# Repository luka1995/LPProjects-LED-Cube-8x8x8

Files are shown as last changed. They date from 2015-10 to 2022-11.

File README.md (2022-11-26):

## LPProjects LED Cube 8x8x8
### 3-Dimensional Display controllable with Smart Phone



Created by Luka Penger<br/>
<br/>
• Real Time controllable via network<br/>
• Universal power supply 5-12V DC<br/>
• Custom animations and effects<br/>
• Drawing with touch in X, Y and Z orientation<br/>
• Programmable sequences<br/>
• WEB interface for quick control<br/>
• Open UDP / TCP protocol<br/>
• Auto start function<br/>
• 32 MB Flash storage for animations<br/>
• Control multiple cubes<br/>
• iPhone / iPod Touch / iPad Application<br/>
• 3D preview animation<br/>
• Share animations with friends<br/>
• Spice up your party!<br/>
<br/>
Connect to your LPProjects LED Cube 8x8x8 with mobile device and makes awesome animations!<br/>

### iOS Application:
Compatible with iPhone 4, iPhone 4S, iPhone 5, iPhone 6, iPhone 6+, iPod touch, iPad. Requires iOS 7.0 or later.
<br/>
Available on: https://itunes.apple.com/us/app/led-cube-8x8x8-controller/id940731753

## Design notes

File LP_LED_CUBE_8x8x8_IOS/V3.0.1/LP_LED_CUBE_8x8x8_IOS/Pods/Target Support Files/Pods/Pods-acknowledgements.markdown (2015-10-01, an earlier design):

# Acknowledgements
This application makes use of the following third party libraries:

## CocoaAsyncSocket

Public Domain License

The CocoaAsyncSocket project is in the public domain.

The original TCP version (AsyncSocket) was created by Dustin Voss in January 2003.
Updated and maintained by Deusty LLC and the Apple development community.

## MBProgressHUD

Copyright (c) 2013 Matej Bukovinski

Permission is hereby granted, free of charge, to any person obtaining a copy
of this software and associated documentation files (the "Software"), to deal
in the Software without restriction, including without limitation the rights
to use, copy, modify, merge, publish, distribute, sublicense, and/or sell
copies of the Software, and to permit persons to whom the Software is
furnished to do so, subject to the following conditions:

The above copyright notice and this permission notice shall be included in
all copies or substantial portions of the Software.

THE SOFTWARE IS PROVIDED "AS IS", WITHOUT WARRANTY OF ANY KIND, EXPRESS OR
IMPLIED, INCLUDING BUT NOT LIMITED TO THE WARRANTIES OF MERCHANTABILITY,
FITNESS FOR A PARTICULAR PURPOSE AND NONINFRINGEMENT. IN NO EVENT SHALL THE
AUTHORS OR COPYRIGHT HOLDERS BE LIABLE FOR ANY CLAIM, DAMAGES OR OTHER
LIABILITY, WHETHER IN AN ACTION OF CONTRACT, TORT OR OTHERWISE, ARISING FROM,
OUT OF OR IN CONNECTION WITH THE SOFTWARE OR THE USE OR OTHER DEALINGS IN
THE SOFTWARE.

## RMPickerViewController

Copyright (c) 2013 Roland Moers

Permission is hereby granted, free of charge, to any person obtaining a copy
of this software and associated documentation files (the "Software"), to deal
in the Software without restriction, including without limitation the rights
to use, copy, modify, merge, publish, distribute, sublicense, and/or sell
copies of the Software, and to permit persons to whom the Software is
furnished to do so, subject to the following conditions:

The above copyright notice and this permission notice shall be included in
all copies or substantial portions of the Software.

THE SOFTWARE IS PROVIDED "AS IS", WITHOUT WARRANTY OF ANY KIND, EXPRESS OR
IMPLIED, INCLUDING BUT NOT LIMITED TO THE WARRANTIES OF MERCHANTABILITY,
FITNESS FOR A PARTICULAR PURPOSE AND NONINFRINGEMENT. IN NO EVENT SHALL THE
AUTHORS OR COPYRIGHT HOLDERS BE LIABLE FOR ANY CLAIM, DAMAGES OR OTHER
LIABILITY, WHETHER IN AN ACTION OF CONTRACT, TORT OR OTHERWISE, ARISING FROM,
OUT OF OR IN CONNECTION WITH THE SOFTWARE OR THE USE OR OTHER DEALINGS IN
THE SOFTWARE.

## Reachability

Copyright (c) 2011, Tony Million.
All rights reserved.

Redistribution and use in source and binary forms, with or without modification, are permitted provided that the following conditions are met:

1. Redistributions of source code must retain the above copyright notice, this list of conditions and the following disclaimer.

2. Redistributions in binary form must reproduce the above copyright notice, this list of conditions and the following disclaimer in the documentation and/or other materials provided with the distribution.

THIS SOFTWARE IS PROVIDED BY THE COPYRIGHT HOLDERS AND CONTRIBUTORS "AS IS" AND ANY EXPRESS OR IMPLIED WARRANTIES, INCLUDING, BUT NOT LIMITED TO, THE IMPLIED WARRANTIES OF MERCHANTABILITY AND FITNESS FOR A PARTICULAR PURPOSE ARE DISCLAIMED. IN NO EVENT SHALL THE COPYRIGHT HOLDER OR CONTRIBUTORS BE LIABLE FOR ANY DIRECT, INDIRECT, INCIDENTAL, SPECIAL, EXEMPLARY, OR CONSEQUENTIAL DAMAGES (INCLUDING, BUT NOT LIMITED TO, PROCUREMENT OF SUBSTITUTE GOODS OR SERVICES; LOSS OF USE, DATA, OR PROFITS; OR BUSINESS INTERRUPTION) HOWEVER CAUSED AND ON ANY THEORY OF LIABILITY, WHETHER IN CONTRACT, STRICT LIABILITY, OR TORT (INCLUDING NEGLIGENCE OR OTHERWISE) ARISING IN ANY WAY OUT OF THE USE OF THIS SOFTWARE, EVEN IF ADVISED OF THE POSSIBILITY OF SUCH DAMAGE. 

Generated by CocoaPods - http://cocoapods.org

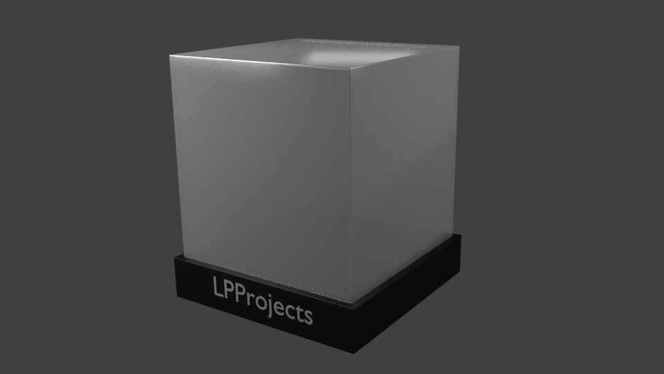
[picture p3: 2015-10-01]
Images/LED_Cube_8x8x8.png

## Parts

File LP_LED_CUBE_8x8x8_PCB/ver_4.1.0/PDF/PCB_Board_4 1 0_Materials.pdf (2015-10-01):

Item | Name / Description | Package | Designator on schematic | Quantity
1 | 74HC574N D-TYPE FLIP-FLOP | DIP-20 | U1, U2, U3, U4, U5, U6, U7, U8 | 8
2 | SI3861BDV Vishay 4.5-20V 2.3A Load Switch | TSOP-6 | U9, U10, U11, U12, U13, U14, U15, U16 | 8
3 | TPS56528 Step-Down Converter 4.5V-18V 5A | HSOP-8 | U17 | 1
4 | 100uH 2A Power Inductor 12x12mm | / | L1 | 1
5 | 3.81mm 2 pin Male Terminal Block Vertical | / | P8 | 1
6 | 2.54mm 2 pin Male Header Jumper | / | W1 | 1
7 | 2.54mm 2x8 pin IDC Female Header Connector | / | P6 | 5
8 | 2.54mm 2x4 pin IDC Female Header Connector | / | P5 | 2
9 | SK54 40V 5A SMC Schottky Diode SMD | SMC | D1 | 1
10 | 3mm LED Red | / | D2 | 1
11 | 220uF 16V Aluminium Electrolytic Capacitor 6.3x7.7mm | / | C25, C28 | 2
12 | 100nF | 0603 | C1, C2, C3, C4, C5, C6, C7, C8, C9, C11, C13, C15, C17, C19, C21, C23, | 18
13 | 1nF | 0603 | C10, C12, C14, C16, C18, C20, C22,C24 | 8
14 | 220uF | 0603 | C30 | 1
15 | 10k | 0603 | R65, R66, R69, R70, R71, R72, R75, R76, R77, R78, R81, R82, R83, R84, R87, R88, | 17
16 | 100R | 0603 | R1, R2, R3, R4, R5, R6, R7, R8, R9, R10, R11, R12, R13, R14, R15, R16, R17, R18, R19, R20, R21, R22, R23, R24, R25, R26, R27, R28, R29, R30, R31, R32, R33, R34, R35, R36, R37, R38, R39, R40, R41, R42, | 64
17 | 0R | 0603 | R67, R68, R73, R74, R79, R80, R85, R86 | 8
18 | 180k | 0603 | R90 | 1
19 | 220k | 0603 | R91 | 1
20 | 49.9k 1% | 0603 | R92 | 1
21 | 100k | 0603 | R93 | 1
22 | 470R | 0603 | R94 | 1

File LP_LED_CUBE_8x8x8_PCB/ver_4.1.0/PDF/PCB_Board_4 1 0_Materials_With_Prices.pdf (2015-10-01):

Item | Name / Description | Package | Designator on schematic | Quantity | Unit Price [Eur] | Part Number | Other
1 | 74HC574N D-TYPE FLIP-FLOP | DIP-20 | U1, U2, U3, U4, U5, U6, U7, U8 | 8 | 0,23 | 9591630 | Farnell
2 | SI3861BDV Vishay 4.5-20V 2.3A Load Switch | TSOP-6 | U9, U10, U11, U12, U13, U14, U15, U16 | 8 | 0,742 | 781-SI3861BDV-T1-E3 | Mouser
3 | TPS56528 Step-Down Converter 4.5V-18V 5A | HSOP-8 | U17 | 1 | 3,56 | 595-TPS56528DDA | Mouser
4 | 100uH 2A Power Inductor 12x12mm | / | L1 | 1 | 0,35 | 390302128027 | Ebay
5 | 3.81mm 2 pin Male Terminal Block Vertical | / | P8 | 1 | 0,25 | 301017793034 | Ebay
6 | 2.54mm 2 pin Male Header Jumper | / | W1 | 1 | 0,1 | 170910122061 | Ebay
7 | 2.54mm 2x8 pin IDC Female Header Connector | / | P6 | 5 | 0,15 | 171048488166 | Ebay
8 | 2.54mm 2x4 pin IDC Female Header Connector | / | P5 | 2 | 0,15 | 171046688738 | Ebay
9 | SK54 40V 5A SMC Schottky Diode SMD | SMC | D1 | 1 | 0,02 | 171055989918 | Ebay
10 | 3mm LED Red | / | D2 | 1 | 0,001 | 290809722053 | Ebay
11 | 220uF 16V Aluminium Electrolytic Capacitor 6.3x7.7mm | / | C25, C28 | 2 | 0,2 | 271673966101 | Ebay
12 | 100nF | 0603 | C1, C2, C3, C4, C5, C6, C7, C8, C9, C11, C13, C15, C17, C19, C21, C23, | 18 | 0,002 | / | Ebay
13 | 1nF | 0603 | C10, C12, C14, C16, C18, C20, C22,C24 | 8 | 0,002 | / | Ebay
14 | 220uF | 0603 | C30 | 1 | 0,002 | / | Ebay
15 | 10k | 0603 | R65, R66, R69, R70, R71, R72, R75, R76, R77, R78, R81, R82, R83, R84, R87, R88, | 17 | 0,002 | / | Ebay
16 | 100R | 0603 | R1, R2, R3, R4, R5, R6, R7, R8, R9, R10, R11, R12, R13, R14, R15, R16, R17, R18, R19, R20, R21, R22, R23, R24, R25, R26, R27, R28, R29, R30, R31, R32, R33, R34, R35, R36, R37, R38, R39, R40, R41, R42, | 64 | 0,002 | / | Ebay
17 | 0R | 0603 | R67, R68, R73, R74, R79, R80, R85, R86 | 8 | 0,002 | / | Ebay
18 | 180k | 0603 | R90 | 1 | 0,002 | / | Ebay
19 | 220k | 0603 | R91 | 1 | 0,002 | / | Ebay
20 | 49.9k 1% | 0603 | R92 | 1 | 0,002 | / | Ebay
21 | 100k | 0603 | R93 | 1 | 0,002 | / | Ebay
22 | 470R | 0603 | R94 | 1 | 0,002 | / | Ebay
All elements | | 13,745
2Layer PCB 10cm x 15cm 1.6mm Green | 1 | 8,8 | / | iTeadStudio
TOTAL IN EUROS: | 22,545

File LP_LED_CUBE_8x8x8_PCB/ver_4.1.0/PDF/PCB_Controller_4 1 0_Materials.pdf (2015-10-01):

Item | Name / Description | Package | Designator on schematic | Quantity
1 | NXP LPC1769FBD100 - 32-bit ARM Cortex-M3 | LQFP-100 | U1 | 1
2 | Texas Instruments TRS3232CDR RS-232 | SOIC 16 Narrow | U2 | 1
3 | Adesto Technologies AT45DB321E-SHF-T | SOIC (EIAJ) 8S2 8 | U3 | 1
4 | Texas Instruments DP83848CVV PHY 10/100 | LQFP-48 | U5 | 1
5 | Texas Instruments LM2671M-3.3 Step Down | SOIC-8 Narrow | U6 | 1
6 | LINK-PP LPJ4514GENL - Ethernet connector | / | P4 | 1
7 | SMT Male Header IDC Connector 1.27mm 2x5 pin | / | P2 | 1
8 | USB Type-B Right Angle Female Connector | / | P3 | 1
9 | RS-232 Female Serial Connector DB9 | / | P1 | 1
10 | 5.5MM x 2.5MM Female DC Connector | / | P7 | 1
11 | 3.81mm 2 pin Male Terminal Block Vertical | / | P8 | 1
12 | 2.54mm 2 pin Male Header Jumper | / | W1 | 1
13 | 2.54mm 2x8 pin IDC Female Header Connector | / | P6 | 1
14 | 2.54mm 2x4 pin IDC Female Header Connector | / | P5 | 1
15 | Tactile Push Button 6x6mm Right Angle | / | S1 | 1
16 | 1N5819 SS14 Schottky Diode SMD | SS14 | D6, D7, D9 | 3
17 | 3mm LED Red | / | D1, D2, D3, D4, D5, D8 | 6
18 | 12 MHz SMD Crystal 5032 5x3.2mm | 5032 | Y2 | 1
19 | 32.768 kHz SMD Crystal FC-135 | FC-135 3.2x1.5mm | Y1 | 1
20 | 50 MHz SMD Oscillator ACT9200 5x7mm | ACT9200 5x7mm | Y3 | 1
23 | 3.6V DC 0.22F Supercapacitor | Bulk | BT1 | 1
24 | 220uF 16V Aluminium Electrolytic Capacitor 6.3x7.7mm | / | C22, C24 | 2
25 | 100nF | 0603 | C1, C2, C3, C4, C9, C10, C11, C14, C15, C16, C17, C18, C19, | 15
26 | 22pF | 0603 | C5, C6, C7, C8 | 4
27 | 18pF | 0603 | C12, C13 | 2
28 | 1uF | 0603 | C20 | 1
29 | 10nF | 0603 | C21 | 1
30 | 10k | 0603 | R1, R3, R4, R5, R6, R7, R8, R29 | 8
31 | 1k | 0603 | R9 | 1
32 | 470R | 0603 | R10, R11, R12, R13, R14, R25, R26, R36 | 8
33 | 1k5 | 0603 | R16 | 1
34 | 33R | 0603 | R17, R18 | 1
34 | 75R 1% | 0603 | R19, R24, R27, R28 | 4
35 | 49R9 1% | 0603 | R20, R21, R22, R23 | 4
36 | 2k2 | 0603 | R30, R31, R32, R33, R34 | 5
37 | 4k7 | 0603 | R35 | 1
38 | 50R | 0805 | R15 | 1

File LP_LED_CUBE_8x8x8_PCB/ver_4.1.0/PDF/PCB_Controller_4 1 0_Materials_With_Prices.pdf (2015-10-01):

Item | Name / Description | Package | Designator on schematic | Quantity | Unit Price [Eur] | Part Number | Other
1 | NXP LPC1769FBD100 - 32-bit ARM Cortex-M3 | LQFP-100 | U1 | 1 | 10,16 | 771-LPC1769FBD100551 | Mouser
2 | Texas Instruments TRS3232CDR RS-232 | SOIC 16 Narrow | U2 | 1 | 1,62 | 595-TRS3232CDR | Mouser
3 | Adesto Technologies AT45DB321E-SHF-T | SOIC (EIAJ) 8S2 8 | U3 | 1 | 2,57 | 988-AT45DB321E-SHF-T | Mouser
4 | Texas Instruments DP83848CVV PHY 10/100 | LQFP-48 | U5 | 1 | 4,69 | 926-DP83848CVVX/NOPB | Mouser
5 | Texas Instruments LM2671M-3.3 Step Down | SOIC-8 Narrow | U6 | 1 | 2,83 | 926-LM2671MX33NOPB | Mouser
6 | LINK-PP LPJ4514GENL - Ethernet connector | / | P4 | 1 | 1,8 | / | LINK-PP
7 | SMT Male Header IDC Connector 1.27mm 2x5 pin | / | P2 | 1 | 0,5 | 171560426679 | Ebay
8 | USB Type-B Right Angle Female Connector | / | P3 | 1 | 0,5 | 280782705985 | Ebay
9 | RS-232 Female Serial Connector DB9 | / | P1 | 1 | 0,2 | 300944843046 | Ebay
10 | 5.5MM x 2.5MM Female DC Connector | / | P7 | 1 | 0,2 | 161271021525 | Ebay
11 | 3.81mm 2 pin Male Terminal Block Vertical | / | P8 | 1 | 0,25 | 301017793034 | Ebay
12 | 2.54mm 2 pin Male Header Jumper | / | W1 | 1 | 0,1 | 170910122061 | Ebay
13 | 2.54mm 2x8 pin IDC Female Header Connector | / | P6 | 1 | 0,15 | 171048488166 | Ebay
14 | 2.54mm 2x4 pin IDC Female Header Connector | / | P5 | 1 | 0,15 | 171046688738 | Ebay
15 | Tactile Push Button 6x6mm Right Angle | / | S1 | 1 | 0,1 | 370412390814 | Ebay
16 | 1N5819 SS14 Schottky Diode SMD | SS14 | D6, D7, D9 | 3 | 0,02 | 191194484047 | Ebay
17 | 3mm LED Red | / | D1, D2, D3, D4, D5, D8 | 6 | 0,001 | 290809722053 | Ebay
18 | 12 MHz SMD Crystal 5032 5x3.2mm | 5032 | Y2 | 1 | 0,25 | 331220814055 | Ebay
19 | 32.768 kHz SMD Crystal FC-135 | FC-135 3.2x1.5mm | Y1 | 1 | 0,25 | 231291006714 | Ebay
20 | 50 MHz SMD Oscillator ACT9200 5x7mm | ACT9200 5x7mm | Y3 | 1 | 0,8 | 121367170907 | Ebay
23 | 3.6V DC 0.22F Supercapacitor | Bulk | BT1 | 1 | 2,4 | 598-EDLRD224H3R6C | Mouser
24 | 220uF 16V Aluminium Electrolytic Capacitor 6.3x7.7mm | / | C22, C24 | 2 | 0,2 | 271673966101 | Ebay
25 | 100nF | 0603 | C1, C2, C3, C4, C9, C10, C11, C14, C15, C16, C17, C18, C19, | 15 | 0,002 | / | /
26 | 22pF | 0603 | C5, C6, C7, C8 | 4 | 0,002 | / | /
27 | 18pF | 0603 | C12, C13 | 2 | 0,002 | / | /
28 | 1uF | 0603 | C20 | 1 | 0,002 | / | /
29 | 10nF | 0603 | C21 | 1 | 0,002 | / | /
30 | 10k | 0603 | R1, R3, R4, R5, R6, R7, R8, R29 | 8 | 0,002 | / | /
31 | 1k | 0603 | R9 | 1 | 0,002 | / | /
32 | 470R | 0603 | R10, R11, R12, R13, R14, R25, R26, R36 | 8 | 0,002 | / | /
33 | 1k5 | 0603 | R16 | 1 | 0,002 | / | /
34 | 33R | 0603 | R17, R18 | 1 | 0,002 | / | /
34 | 75R 1% | 0603 | R19, R24, R27, R28 | 4 | 0,002 | / | /
35 | 49R9 1% | 0603 | R20, R21, R22, R23 | 4 | 0,002 | / | /
36 | 2k2 | 0603 | R30, R31, R32, R33, R34 | 5 | 0,002 | / | /
37 | 4k7 | 0603 | R35 | 1 | 0,002 | / | /
38 | 50R | 0805 | R15 | 1 | 0,002 | / | /
All elements | | 30,1
2Layer PCB 10cm x 15cm 1.6mm Green | 1 | 8,8 | / | iTeadStudio
TOTAL IN EUROS: | 38,9

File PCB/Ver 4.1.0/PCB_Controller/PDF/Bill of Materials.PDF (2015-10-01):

Bill of Materials | Bill of Materials For Project [LP_LED_CUBE_8x8x8.PrjPcb] (No PCB Document Selected)
Source Data From: | LP_LED_CUBE_8x8x8.PrjPcb
Project: | | LP_LED_CUBE_8x8x8.PrjPcb
Variant: | | None
Creation Date: 30/12/14 | 00:37:15
Print Date: | 30-Dec-14 | 12:37:18 am
#Column Name Comment | #Column Name ErrDesignato r | Description | Quantity

Battery | BT1 | Multicell Battery | 1
100n | C1, C2, C3, C4, C9, C10, C11, C14, C15,
| C16, C17, C18, C19, C23, C25 | Capacitor | 15
22p | C5, C6, C7, C8 | Capacitor | 4
18p | C12, C13 | Capacitor | 2
1uF | C20 | Capacitor | 1
10n | C21 | Capacitor | 1
220uF | C22, C24 | Capacitor | 2
USB LED | D1 | Typical INFRARED GaAs LED | 1
LED1 | D2 | Typical INFRARED GaAs LED | 1
LED2 | D3 | Typical INFRARED GaAs LED | 1
LED4 | D4 | Typical INFRARED GaAs LED | 1
LED5 | D5 | Typical INFRARED GaAs LED | 1
1N5819 | D6, D7, D9 | Schottky Diode | 3
POWER LED | D8 | Typical INFRARED GaAs LED | 1
100uH | L1 | Inductor | 1
RS232 | P1 | Receptacle Assembly, 9 Position, Right
| | Angle | 1
JTAG Connector ULINK | P2 | JTAG Connector | 1
USB B | P3 | USB Connector | 1
RJ45 Ethernet | P4 | Ethernet Connector | 1
LED Layers Connector | P5 | Header, 4-Pin, Dual row | 1
LED Connector | P6 | Header, 8-Pin, Dual row | 1
DC Connector | P7 | DC Power Connector | 1
Power to board | P8 | Header, 2-Pin | 1
10k | R1, R3, R4, R5, R6, R7, R8, R29 | Resistor | 8
NO | R2 | Resistor | 1
1k | R9 | Resistor | 1
470R | R10, R11, R12, R13, R14, R25, R26, R36 | Resistor | 8
50R | R15 | Resistor | 1
1k5 | R16 | Resistor | 1
33R | R17, R18 | Resistor | 2
75R 1% | R19, R24, R27, R28 | Resistor | 4
49R9 1% | R20, R21, R22, R23 | Resistor | 4
2k2 | R30, R31, R32, R33, R34 | Resistor | 5
4k7 | R35 | Resistor | 1
FW Update | S1 | Switch | 1
LPC1769FBD10
0 | U1 | 32-bit ARM Cortex-M3 microcontroller; up to
| | 512 kB flash and 64 kB SRAM with
| | Ethernet, USB 2.0 Host/Device/OTG, CAN | 1
TRS3232 | U2 | Dual 232 +3V3 | 1
AT45DB321E | U3 | SPI Flash 32MB | 1
DP83848C | U4 | Ethernet PHY | 1
LM2671 - 3.3V | U5 | Switcher Voltage Regulator | 1
Jumper | W1 | Jumper Wire | 1
32.768 kHz | Y1 | Crystal Oscillator | 1
12 MHz | Y2 | Crystal Oscillator | 1
50 MHz | Y3 | | 1
Approved Notes | 90

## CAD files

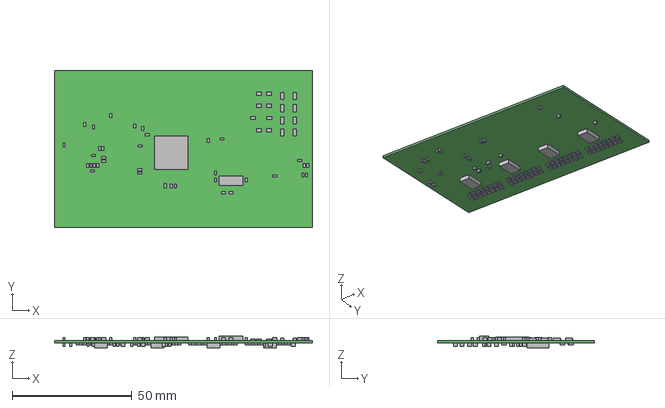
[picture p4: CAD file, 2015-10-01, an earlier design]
LP_LED_CUBE_8x8x8_PCB/ver_1.0.0/Project Outputs for LP_LED_CUBE_8x8x8/ExportSTEP/LP_LED_CUBE_8x8x8.step
107.7 x 65.5 x 4.98 mm
Board
Extruded x 142

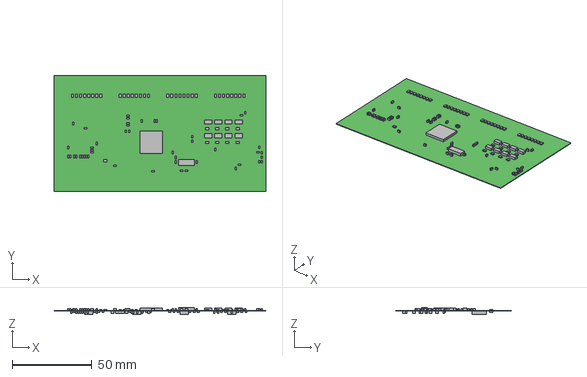
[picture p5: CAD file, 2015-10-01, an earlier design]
LP_LED_CUBE_8x8x8_PCB/ver_2.0.0/Project Outputs for LP_LED_CUBE_8x8x8/ExportSTEP/LP_LED_CUBE_8x8x8.step
132.7 x 72.6 x 4.30 mm
Board
Extruded x 157

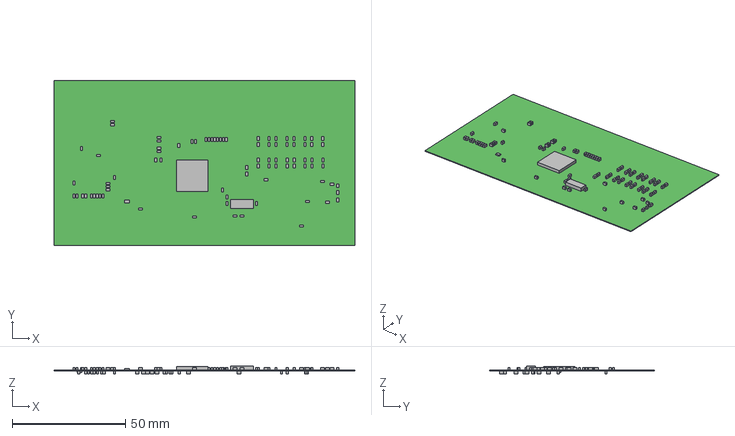
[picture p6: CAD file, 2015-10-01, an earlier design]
LP_LED_CUBE_8x8x8_PCB/ver_3.0.0/Project Outputs for LP_LED_CUBE_8x8x8/ExportSTEP/LP_LED_CUBE_8x8x8.step
132.7 x 72.6 x 3.60 mm
Board
Extruded x 117

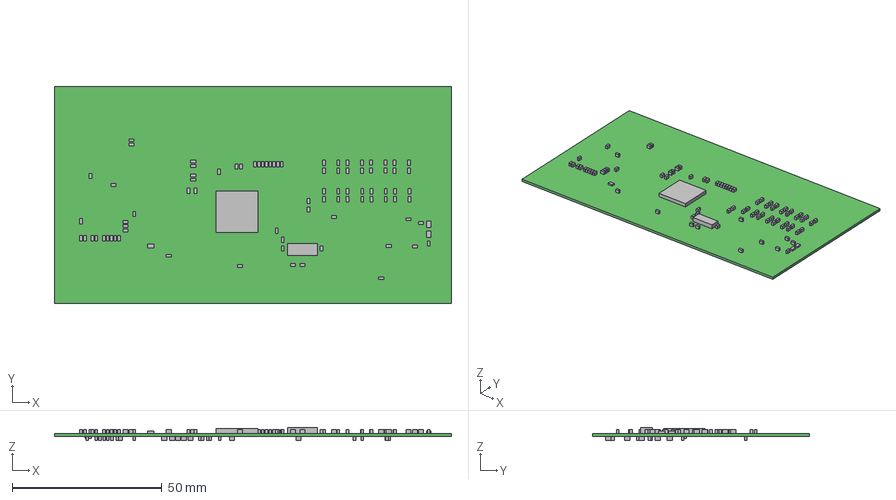
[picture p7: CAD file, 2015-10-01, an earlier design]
LP_LED_CUBE_8x8x8_PCB/ver_3.0.1/Project Outputs for LP_LED_CUBE_8x8x8/ExportSTEP/LP_LED_CUBE_8x8x8.step
132.7 x 72.6 x 4.28 mm
Board
Extruded x 117

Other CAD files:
LP_LED_CUBE_8x8x8_PCB/ver_4.0.0/PCB_Controller/Project Outputs for LP_LED_CUBE_8x8x8/ExportSTEP/LP_LED_CUBE_8x8x8.step
Images/LED_Cube_8x8x8.blend
Images/LED_Cube_Preview_V2.blend

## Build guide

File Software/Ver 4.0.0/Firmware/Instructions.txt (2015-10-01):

LPProjects LED Cube 8x8x8 Controller Firmware - Instructions

Version: 4.0.0

==================================================================

Changes in this version:
-	This is release version.

==================================================================

Hardware configuration/requirements:
-	A USB cable "Type B" to power the board and to access the USB Bootloader.

How to run Bootloader:
	1.	Connect USB cable “Type B” to Controller and Computer.
	2.	Hold the Firmware-Update/Reset button.
	3.	Connect the power to Controller.
	4.	Release the Firmware-Update/Reset button.
	
	5.	On the Computer you will see new MSC drive
	6.	Open the new MSC drive showing in “My Computer” (Windows workstation).
	7.	Delete the default “firmware.bin” file.
	8.	Copy the new binary (.bin) file on the drive.
	9.	Remove power supply from Controller.
	10.	Connect the power to Controller again.

	Now you have a new version of firmware loaded on the Controller.

==================================================================

Luka Penger 2014
http://lukapenger.eu

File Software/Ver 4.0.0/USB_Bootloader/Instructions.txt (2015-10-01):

LPProjects LED Cube 8x8x8 Controller USB Bootloader - Instructions

Version: 4.0.0

==================================================================

Hardware configuration/requirements:
-	Connect JTAG to 5x2 pin connector.

How to program .hex to Controlller:

-	You may create a µVision3 project for Flash download of a HEX file as described below:

-	Create a µVision project file with the menu command Project — New Project....

-	Select the microcontroller for your project from the Device Database, but do not copy any Startup Code to this project.

-	In the dialog Project — Options for Target — Output enter the HEX file name as Name of Executable.

-	Setup the download utility as described under Configure Flash Menu.

-	Flash Download Button

-	When using the Flash — Download command, µVision is programming the specified HEX file into the Flash ROM device.

==================================================================

Luka Penger 2014
http://lukapenger.eu

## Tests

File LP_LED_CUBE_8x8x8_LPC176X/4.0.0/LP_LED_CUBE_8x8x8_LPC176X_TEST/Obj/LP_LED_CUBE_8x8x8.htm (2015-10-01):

# Static Call Graph for image .\Obj\LP_LED_CUBE_8x8x8.axf

#<CALLGRAPH># ARM Linker, 5.03 [Build 76]: Last Updated: Sat Nov 29 20:14:07 2014

### Maximum Stack Usage = 80 bytes + Unknown(Functions without stacksize, Cycles, Untraceable Function Pointers)

### Call chain for Maximum Stack Depth:

__rt_entry_main ⇒ main ⇒ LED_CUBE_Animation_String_belt ⇒ LED_CUBE_Animation_Set_char_to_belt ⇒ tolower ⇒ __rt_ctype_table

### Functions with no stack information

- __user_initial_stackheap

### Mutually Recursive functions

- NMI_Handler ⇒ NMI_Handler
- HardFault_Handler ⇒ HardFault_Handler
- MemManage_Handler ⇒ MemManage_Handler
- BusFault_Handler ⇒ BusFault_Handler
- UsageFault_Handler ⇒ UsageFault_Handler
- SVC_Handler ⇒ SVC_Handler
- DebugMon_Handler ⇒ DebugMon_Handler
- PendSV_Handler ⇒ PendSV_Handler
- ADC_IRQHandler ⇒ ADC_IRQHandler

### Function Pointers

- ADC_IRQHandler from startup_lpc17xx.o(.text) referenced from startup_lpc17xx.o(RESET)
- BOD_IRQHandler from startup_lpc17xx.o(.text) referenced from startup_lpc17xx.o(RESET)
- BusFault_Handler from startup_lpc17xx.o(.text) referenced from startup_lpc17xx.o(RESET)
- CANActivity_IRQHandler from startup_lpc17xx.o(.text) referenced from startup_lpc17xx.o(RESET)
- CAN_IRQHandler from startup_lpc17xx.o(.text) referenced from startup_lpc17xx.o(RESET)
- DMA_IRQHandler from startup_lpc17xx.o(.text) referenced from startup_lpc17xx.o(RESET)
- DebugMon_Handler from startup_lpc17xx.o(.text) referenced from startup_lpc17xx.o(RESET)
- EINT0_IRQHandler from startup_lpc17xx.o(.text) referenced from startup_lpc17xx.o(RESET)
- EINT1_IRQHandler from startup_lpc17xx.o(.text) referenced from startup_lpc17xx.o(RESET)
- EINT2_IRQHandler from startup_lpc17xx.o(.text) referenced from startup_lpc17xx.o(RESET)
- EINT3_IRQHandler from startup_lpc17xx.o(.text) referenced from startup_lpc17xx.o(RESET)
- ENET_IRQHandler from startup_lpc17xx.o(.text) referenced from startup_lpc17xx.o(RESET)
- HardFault_Handler from startup_lpc17xx.o(.text) referenced from startup_lpc17xx.o(RESET)
- I2C0_IRQHandler from startup_lpc17xx.o(.text) referenced from startup_lpc17xx.o(RESET)
- I2C1_IRQHandler from startup_lpc17xx.o(.text) referenced from startup_lpc17xx.o(RESET)
- I2C2_IRQHandler from startup_lpc17xx.o(.text) referenced from startup_lpc17xx.o(RESET)
- I2S_IRQHandler from startup_lpc17xx.o(.text) referenced from startup_lpc17xx.o(RESET)
- MCPWM_IRQHandler from startup_lpc17xx.o(.text) referenced from startup_lpc17xx.o(RESET)
- MemManage_Handler from startup_lpc17xx.o(.text) referenced from startup_lpc17xx.o(RESET)
- NMI_Handler from startup_lpc17xx.o(.text) referenced from startup_lpc17xx.o(RESET)
- PLL0_IRQHandler from startup_lpc17xx.o(.text) referenced from startup_lpc17xx.o(RESET)
- PLL1_IRQHandler from startup_lpc17xx.o(.text) referenced from startup_lpc17xx.o(RESET)
- PWM1_IRQHandler from startup_lpc17xx.o(.text) referenced from startup_lpc17xx.o(RESET)
- PendSV_Handler from startup_lpc17xx.o(.text) referenced from startup_lpc17xx.o(RESET)
- QEI_IRQHandler from startup_lpc17xx.o(.text) referenced from startup_lpc17xx.o(RESET)
- RIT_IRQHandler from startup_lpc17xx.o(.text) referenced from startup_lpc17xx.o(RESET)
- RTC_IRQHandler from startup_lpc17xx.o(.text) referenced from startup_lpc17xx.o(RESET)
- Reset_Handler from startup_lpc17xx.o(.text) referenced from startup_lpc17xx.o(RESET)
- SPI_IRQHandler from startup_lpc17xx.o(.text) referenced from startup_lpc17xx.o(RESET)
- SSP0_IRQHandler from startup_lpc17xx.o(.text) referenced from startup_lpc17xx.o(RESET)
- SSP1_IRQHandler from startup_lpc17xx.o(.text) referenced from startup_lpc17xx.o(RESET)
- SVC_Handler from startup_lpc17xx.o(.text) referenced from startup_lpc17xx.o(RESET)
- SysTick_Handler from main.o(.text) referenced from startup_lpc17xx.o(RESET)
- SystemInit from system_lpc17xx.o(.text) referenced from startup_lpc17xx.o(.text)
- TIMER0_IRQHandler from startup_lpc17xx.o(.text) referenced from startup_lpc17xx.o(RESET)
- TIMER1_IRQHandler from startup_lpc17xx.o(.text) referenced from startup_lpc17xx.o(RESET)
- TIMER2_IRQHandler from startup_lpc17xx.o(.text) referenced from startup_lpc17xx.o(RESET)
- TIMER3_IRQHandler from startup_lpc17xx.o(.text) referenced from startup_lpc17xx.o(RESET)
- UART0_IRQHandler from uart.o(.text) referenced from startup_lpc17xx.o(RESET)
- UART1_IRQHandler from uart.o(.text) referenced from startup_lpc17xx.o(RESET)
- UART2_IRQHandler from startup_lpc17xx.o(.text) referenced from startup_lpc17xx.o(RESET)
- UART3_IRQHandler from startup_lpc17xx.o(.text) referenced from startup_lpc17xx.o(RESET)
- USBActivity_IRQHandler from startup_lpc17xx.o(.text) referenced from startup_lpc17xx.o(RESET)
- USB_IRQHandler from startup_lpc17xx.o(.text) referenced from startup_lpc17xx.o(RESET)
- UsageFault_Handler from startup_lpc17xx.o(.text) referenced from startup_lpc17xx.o(RESET)
- WDT_IRQHandler from startup_lpc17xx.o(.text) referenced from startup_lpc17xx.o(RESET)
- __main from __main.o(!!!main) referenced from startup_lpc17xx.o(.text)
- _get_lc_ctype from lc_ctype_c.o(locale$$code) referenced from rt_ctype_table.o(.text)

### Global Symbols

__main (Thumb, 8 bytes, Stack size 0 bytes, __main.o(!!!main))

[Calls]

- >> __rt_entry
- >> __scatterload

__scatterload (Thumb, 0 bytes, Stack size unknown bytes, __scatter.o(!!!scatter))

[Called By]

- >> __main

__scatterload_rt2 (Thumb, 44 bytes, Stack size unknown bytes, __scatter.o(!!!scatter), UNUSED)

[Calls]

- >> __rt_entry

__scatterload_rt2_thumb_only (Thumb, 0 bytes, Stack size unknown bytes, __scatter.o(!!!scatter), UNUSED)

__scatterload_null (Thumb, 0 bytes, Stack size unknown bytes, __scatter.o(!!!scatter), UNUSED)

__scatterload_copy (Thumb, 26 bytes, Stack size unknown bytes, __scatter_copy.o(!!handler_copy), UNUSED)

[Calls]

- >> __scatterload_copy

[Called By]

- >> __scatterload_copy

__scatterload_zeroinit (Thumb, 28 bytes, Stack size unknown bytes, __scatter_zi.o(!!handler_zi), UNUSED)

__rt_lib_init (Thumb, 0 bytes, Stack size unknown bytes, libinit.o(.ARM.Collect$$libinit$$00000000))

[Called By]

- >> __rt_entry_li

__rt_lib_init_fp_1 (Thumb, 0 bytes, Stack size unknown bytes, libinit2.o(.ARM.Collect$$libinit$$00000002))

__rt_lib_init_heap_1 (Thumb, 0 bytes, Stack size unknown bytes, libinit2.o(.ARM.Collect$$libinit$$00000008))

__rt_lib_init_rand_2 (Thumb, 0 bytes, Stack size unknown bytes, libinit2.o(.ARM.Collect$$libinit$$0000000B))

[Stack]

- Max Depth = 8 + Unknown Stack Size
- Call Chain = __rt_lib_init_rand_2 ⇒ _rand_init ⇒ srand

[Calls]

- >> _rand_init

__rt_lib_init_user_alloc_1 (Thumb, 0 bytes, Stack size unknown bytes, libinit2.o(.ARM.Collect$$libinit$$0000000A))

__rt_lib_init_lc_common (Thumb, 0 bytes, Stack size unknown bytes, libinit2.o(.ARM.Collect$$libinit$$0000000D))

[Calls]

- >> __rt_locale

__rt_lib_init_rand_1 (Thumb, 0 bytes, Stack size unknown bytes, libinit2.o(.ARM.Collect$$libinit$$0000000C))

__rt_lib_init_lc_collate_1 (Thumb, 0 bytes, Stack size unknown bytes, libinit2.o(.ARM.Collect$$libinit$$0000000F))

__rt_lib_init_lc_ctype_2 (Thumb, 0 bytes, Stack size unknown bytes, libinit2.o(.ARM.Collect$$libinit$$00000010))

[Stack]

- Max Depth = 8 + Unknown Stack Size
- Call Chain = __rt_lib_init_lc_ctype_2 ⇒ _get_lc_ctype

[Calls]

- >> _get_lc_ctype

__rt_lib_init_alloca_1 (Thumb, 0 bytes, Stack size unknown bytes, libinit2.o(.ARM.Collect$$libinit$$0000002C))

__rt_lib_init_argv_1 (Thumb, 0 bytes, Stack size unknown bytes, libinit2.o(.ARM.Collect$$libinit$$0000002A))

__rt_lib_init_atexit_1 (Thumb, 0 bytes, Stack size unknown bytes, libinit2.o(.ARM.Collect$$libinit$$00000019))

__rt_lib_init_clock_1 (Thumb, 0 bytes, Stack size unknown bytes, libinit2.o(.ARM.Collect$$libinit$$0000001F))

__rt_lib_init_cpp_1 (Thumb, 0 bytes, Stack size unknown bytes, libinit2.o(.ARM.Collect$$libinit$$00000030))

__rt_lib_init_exceptions_1 (Thumb, 0 bytes, Stack size unknown bytes, libinit2.o(.ARM.Collect$$libinit$$0000002E))

__rt_lib_init_fp_trap_1 (Thumb, 0 bytes, Stack size unknown bytes, libinit2.o(.ARM.Collect$$libinit$$0000001D))

__rt_lib_init_getenv_1 (Thumb, 0 bytes, Stack size unknown bytes, libinit2.o(.ARM.Collect$$libinit$$00000021))

__rt_lib_init_lc_ctype_1 (Thumb, 0 bytes, Stack size unknown bytes, libinit2.o(.ARM.Collect$$libinit$$00000011))

__rt_lib_init_lc_monetary_1 (Thumb, 0 bytes, Stack size unknown bytes, libinit2.o(.ARM.Collect$$libinit$$00000013))

__rt_lib_init_lc_numeric_1 (Thumb, 0 bytes, Stack size unknown bytes, libinit2.o(.ARM.Collect$$libinit$$00000015))

__rt_lib_init_lc_time_1 (Thumb, 0 bytes, Stack size unknown bytes, libinit2.o(.ARM.Collect$$libinit$$00000017))

__rt_lib_init_return (Thumb, 0 bytes, Stack size unknown bytes, libinit2.o(.ARM.Collect$$libinit$$00000031))

__rt_lib_init_signal_1 (Thumb, 0 bytes, Stack size unknown bytes, libinit2.o(.ARM.Collect$$libinit$$0000001B))

__rt_lib_init_stdio_1 (Thumb, 0 bytes, Stack size unknown bytes, libinit2.o(.ARM.Collect$$libinit$$00000023))

__rt_lib_shutdown (Thumb, 0 bytes, Stack size unknown bytes, libshutdown.o(.ARM.Collect$$libshutdown$$00000000))

[Called By]

- >> __rt_exit_ls

__rt_lib_shutdown_fp_trap_1 (Thumb, 0 bytes, Stack size unknown bytes, libshutdown2.o(.ARM.Collect$$libshutdown$$00000006))

__rt_lib_shutdown_heap_1 (Thumb, 0 bytes, Stack size unknown bytes, libshutdown2.o(.ARM.Collect$$libshutdown$$0000000E))

__rt_lib_shutdown_return (Thumb, 0 bytes, Stack size unknown bytes, libshutdown2.o(.ARM.Collect$$libshutdown$$0000000F))

__rt_lib_shutdown_signal_1 (Thumb, 0 bytes, Stack size unknown bytes, libshutdown2.o(.ARM.Collect$$libshutdown$$00000009))

__rt_lib_shutdown_stdio_1 (Thumb, 0 bytes, Stack size unknown bytes, libshutdown2.o(.ARM.Collect$$libshutdown$$00000003))

__rt_lib_shutdown_user_alloc_1 (Thumb, 0 bytes, Stack size unknown bytes, libshutdown2.o(.ARM.Collect$$libshutdown$$0000000B))

__rt_entry (Thumb, 0 bytes, Stack size unknown bytes, rtentry.o(.ARM.Collect$$rtentry$$00000000))

[Called By]

- >> __main
- >> __scatterload_rt2

__rt_entry_presh_1 (Thumb, 0 bytes, Stack size unknown bytes, rtentry2.o(.ARM.Collect$$rtentry$$00000002))

__rt_entry_sh (Thumb, 0 bytes, Stack size unknown bytes, rtentry4.o(.ARM.Collect$$rtentry$$00000004))

[Stack]

- Max Depth = 8 + Unknown Stack Size
- Call Chain = __rt_entry_sh ⇒ __user_setup_stackheap

[Calls]

- >> __user_setup_stackheap

__rt_entry_li (Thumb, 0 bytes, Stack size unknown bytes, rtentry2.o(.ARM.Collect$$rtentry$$0000000A))

[Calls]

- >> __rt_lib_init

__rt_entry_postsh_1 (Thumb, 0 bytes, Stack size unknown bytes, rtentry2.o(.ARM.Collect$$rtentry$$00000009))

__rt_entry_main (Thumb, 0 bytes, Stack size unknown bytes, rtentry2.o(.ARM.Collect$$rtentry$$0000000D))

[Stack]

- Max Depth = 80 + Unknown Stack Size
- Call Chain = __rt_entry_main ⇒ main ⇒ LED_CUBE_Animation_String_belt ⇒ LED_CUBE_Animation_Set_char_to_belt ⇒ tolower ⇒ __rt_ctype_table

[Calls]

- >> main
- >> exit

__rt_entry_postli_1 (Thumb, 0 bytes, Stack size unknown bytes, rtentry2.o(.ARM.Collect$$rtentry$$0000000C))

__rt_exit (Thumb, 0 bytes, Stack size unknown bytes, rtexit.o(.ARM.Collect$$rtexit$$00000000))

[Called By]

- >> exit

__rt_exit_ls (Thumb, 0 bytes, Stack size unknown bytes, rtexit2.o(.ARM.Collect$$rtexit$$00000003))

[Calls]

- >> __rt_lib_shutdown

__rt_exit_prels_1 (Thumb, 0 bytes, Stack size unknown bytes, rtexit2.o(.ARM.Collect$$rtexit$$00000002))

__rt_exit_exit (Thumb, 0 bytes, Stack size unknown bytes, rtexit2.o(.ARM.Collect$$rtexit$$00000004))

[Calls]

- >> _sys_exit

rand (Thumb, 48 bytes, Stack size 0 bytes, rand.o(.emb_text), UNUSED)

[Called By]

- >> LED_CUBE_Animations_Cube_invaders
- >> LED_CUBE_Animations_Cube_sonic
- >> LED_CUBE_Animations_Cube_stars
- >> LED_CUBE_Animation_Cube_2_auto
- >> LED_CUBE_Random

UART_CONSOLE_Init (Thumb, 10 bytes, Stack size 0 bytes, main.o(.text))

[Stack]

- Max Depth = 32
- Call Chain = UART_CONSOLE_Init ⇒ UART_Init

[Calls]

- >> UART_Init

[Called By]

- >> Init

UART_CONSOLE_Send_Buffer (Thumb, 10 bytes, Stack size 0 bytes, main.o(.text), UNUSED)

[Calls]

- >> UART_SendBuffer

UART_CONSOLE_Send_String (Thumb, 22 bytes, Stack size 8 bytes, main.o(.text))

[Stack]

- Max Depth = 32
- Call Chain = UART_CONSOLE_Send_String ⇒ UART_SendBuffer ⇒ UART_SendChar

[Calls]

- >> strlen
- >> UART_SendBuffer

[Called By]

- >> Init

UART_CONSOLE_Send_Char (Thumb, 8 bytes, Stack size 0 bytes, main.o(.text), UNUSED)

[Calls]

- >> UART_SendChar

Status_LEDs_Init (Thumb, 36 bytes, Stack size 0 bytes, main.o(.text))

[Called By]

- >> Init

Status_LED1_Set (Thumb, 24 bytes, Stack size 0 bytes, main.o(.text))

[Called By]

- >> main
- >> Status_LED1_Toggle

Status_LED2_Set (Thumb, 24 bytes, Stack size 0 bytes, main.o(.text))

[Called By]

- >> main
- >> Status_LED2_Toggle

Status_LED1_Toggle (Thumb, 10 bytes, Stack size 0 bytes, main.o(.text), UNUSED)

[Calls]

- >> Status_LED1_Set

Status_LED2_Toggle (Thumb, 10 bytes, Stack size 0 bytes, main.o(.text), UNUSED)

[Calls]

- >> Status_LED2_Set

SysTick_Handler (Thumb, 94 bytes, Stack size 16 bytes, main.o(.text))

[Stack]

- Max Depth = 32
- Call Chain = SysTick_Handler ⇒ LED_CUBE_Timer

[Calls]

- >> LED_CUBE_Timer

[Address Reference Count : 1]

- startup_lpc17xx.o(RESET)

Init (Thumb, 66 bytes, Stack size 8 bytes, main.o(.text))

[Stack]

- Max Depth = 40
- Call Chain = Init ⇒ UART_CONSOLE_Send_String ⇒ UART_SendBuffer ⇒ UART_SendChar

[Calls]

- >> SystemInit
- >> LED_CUBE_Init
- >> Status_LEDs_Init
- >> UART_CONSOLE_Send_String
- >> UART_CONSOLE_Init

[Called By]

- >> main

main (Thumb, 70 bytes, Stack size 0 bytes, main.o(.text))

[Stack]

- Max Depth = 80
- Call Chain = main ⇒ LED_CUBE_Animation_String_belt ⇒ LED_CUBE_Animation_Set_char_to_belt ⇒ tolower ⇒ __rt_ctype_table

[Calls]

- >> LED_CUBE_Animations_wipe
- >> LED_CUBE_Animations_Cubes_4
- >> LED_CUBE_Animations_Cube_waves
- >> LED_CUBE_Animation_String_to_front
- >> LED_CUBE_Animation_String_belt
- >> Init
- >> Status_LED2_Set
- >> Status_LED1_Set

[Called By]

- >> __rt_entry_main

LED_CUBE_Layers_Set (Thumb, 180 bytes, Stack size 0 bytes, led_cube_8x8x8.o(.text))

[Called By]

- >> LED_CUBE_Frame_show
- >> LED_CUBE_Timer

LED_CUBE_Layer_Set (Thumb, 172 bytes, Stack size 0 bytes, led_cube_8x8x8.o(.text))

[Called By]

- >> LED_CUBE_Frame_show
- >> LED_CUBE_Timer

LED_CUBE_Clock_Set (Thumb, 168 bytes, Stack size 0 bytes, led_cube_8x8x8.o(.text))

[Called By]

- >> LED_CUBE_Frame_show
- >> LED_CUBE_Timer

LED_CUBE_Outputs_Set (Thumb, 196 bytes, Stack size 0 bytes, led_cube_8x8x8.o(.text))

[Called By]

- >> LED_CUBE_Frame_show
- >> LED_CUBE_Timer

LED_CUBE_Frame_show (Thumb, 92 bytes, Stack size 24 bytes, led_cube_8x8x8.o(.text), UNUSED)

[Calls]

- >> Delay_us
- >> LED_CUBE_Outputs_Set
- >> LED_CUBE_Clock_Set
- >> LED_CUBE_Layer_Set
- >> LED_CUBE_Layers_Set

LED_CUBE_Timer (Thumb, 98 bytes, Stack size 16 bytes, led_cube_8x8x8.o(.text))

[Stack]

- Max Depth = 16
- Call Chain = LED_CUBE_Timer

[Calls]

- >> Delay_us
- >> LED_CUBE_Outputs_Set
- >> LED_CUBE_Clock_Set
- >> LED_CUBE_Layer_Set
- >> LED_CUBE_Layers_Set

[Called By]

- >> SysTick_Handler

LED_CUBE_Clear (Thumb, 30 bytes, Stack size 8 bytes, led_cube_8x8x8.o(.text))

[Stack]

- Max Depth = 8
- Call Chain = LED_CUBE_Clear

[Called By]

- >> rotate_90_deg
- >> rotate_90_auto
- >> LED_CUBE_Animations_Cube_stripes
- >> LED_CUBE_Animations_Cube_invaders
- >> LED_CUBE_Animations_Show_belt
- >> LED_CUBE_Animtions_Outline_shrink
- >> LED_CUBE_Animations_Cube_sonic
- >> LED_CUBE_Animations_Cube_Outline
- >> LED_CUBE_Animations_Cube_stars
- >> LED_CUBE_Animations_Outline_shrink
- >> LED_CUBE_Animations_Cubes_2
- >> LED_CUBE_Animation_Cube_2_auto
- >> LED_CUBE_Animation_Set_char_to_belt
- >> LED_CUBE_Animation_Show_belt
- >> LED_CUBE_Init
- >> LED_CUBE_Animations_Cubes_4
- >> LED_CUBE_Animations_Cube_waves
- >> LED_CUBE_Animation_String_to_front

LED_CUBE_Clear_layer (Thumb, 20 bytes, Stack size 0 bytes, led_cube_8x8x8.o(.text), UNUSED)

[Called By]

- >> LED_CUBE_Animations_Cube_2_auto_show

LED_CUBE_Full (Thumb, 30 bytes, Stack size 8 bytes, led_cube_8x8x8.o(.text), UNUSED)

LED_CUBE_Cube_3 (Thumb, 38 bytes, Stack size 0 bytes, led_cube_8x8x8.o(.text), UNUSED)

LED_CUBE_Cube_4_line (Thumb, 32 bytes, Stack size 0 bytes, led_cube_8x8x8.o(.text), UNUSED)

LED_CUBE_Random (Thumb, 48 bytes, Stack size 24 bytes, led_cube_8x8x8.o(.text), UNUSED)

[Calls]

- >> rand

LED_CUBE_Test_z (Thumb, 30 bytes, Stack size 8 bytes, led_cube_8x8x8.o(.text), UNUSED)

LED_CUBE_Test_y (Thumb, 16 bytes, Stack size 0 bytes, led_cube_8x8x8.o(.text))

[Called By]

- >> LED_CUBE_Animations_wipe

LED_CUBE_Test_x (Thumb, 18 bytes, Stack size 0 bytes, led_cube_8x8x8.o(.text), UNUSED)

LED_CUBE_Clocks_Set (Thumb, 180 bytes, Stack size 0 bytes, led_cube_8x8x8.o(.text), UNUSED)

LED_CUBE_Init (Thumb, 90 bytes, Stack size 0 bytes, led_cube_8x8x8.o(.text))

[Stack]

- Max Depth = 8
- Call Chain = LED_CUBE_Init ⇒ LED_CUBE_Clear

[Calls]

- >> LED_CUBE_Clear

[Called By]

- >> Init

LED_CUBE_Animation_Char (Thumb, 3550 bytes, Stack size 0 bytes, led_cube_8x8x8_animations.o(.text))

[Called By]

- >> LED_CUBE_Animation_Set_char_to_belt
- >> LED_CUBE_Animation_String_to_front

LED_CUBE_Animation_String_to_front (Thumb, 54 bytes, Stack size 16 bytes, led_cube_8x8x8_animations.o(.text))

[Stack]

- Max Depth = 32
- Call Chain = LED_CUBE_Animation_String_to_front ⇒ tolower ⇒ __rt_ctype_table

[Calls]

- >> tolower
- >> Delay_ms
- >> LED_CUBE_Animation_Char
- >> LED_CUBE_Clear

[Called By]

- >> main

LED_CUBE_Animation_Move_belt_left (Thumb, 22 bytes, Stack size 0 bytes, led_cube_8x8x8_animations.o(.text))

[Called By]

- >> LED_CUBE_Animation_String_belt

LED_CUBE_Animation_Show_belt (Thumb, 154 bytes, Stack size 24 bytes, led_cube_8x8x8_animations.o(.text))

[Stack]

- Max Depth = 32
- Call Chain = LED_CUBE_Animation_Show_belt ⇒ LED_CUBE_Clear

[Calls]

- >> Delay_ms
- >> LED_CUBE_Clear

[Called By]

- >> LED_CUBE_Animation_String_belt

LED_CUBE_Animation_Set_char_to_belt (Thumb, 82 bytes, Stack size 24 bytes, led_cube_8x8x8_animations.o(.text))

[Stack]

- Max Depth = 40
- Call Chain = LED_CUBE_Animation_Set_char_to_belt ⇒ tolower ⇒ __rt_ctype_table

[Calls]

- >> tolower
- >> LED_CUBE_Animation_Char
- >> LED_CUBE_Clear

[Called By]

- >> LED_CUBE_Animation_String_belt

LED_CUBE_Animation_String_belt (Thumb, 80 bytes, Stack size 40 bytes, led_cube_8x8x8_animations.o(.text))

[Stack]

- Max Depth = 80
- Call Chain = LED_CUBE_Animation_String_belt ⇒ LED_CUBE_Animation_Set_char_to_belt ⇒ tolower ⇒ __rt_ctype_table

[Calls]

- >> LED_CUBE_Animation_Set_char_to_belt
- >> LED_CUBE_Animation_Show_belt
- >> LED_CUBE_Animation_Move_belt_left

[Called By]

- >> main

LED_CUBE_Animations_Cube_2_auto_show (Thumb, 164 bytes, Stack size 32 bytes, led_cube_8x8x8_animations.o(.text), UNUSED)

[Calls]

- >> Delay_ms
- >> LED_CUBE_Clear_layer

[Called By]

- >> LED_CUBE_Animation_Cube_2_auto

LED_CUBE_Animations_Cube2_move_z_rev (Thumb, 36 bytes, Stack size 16 bytes, led_cube_8x8x8_animations.o(.text), UNUSED)

[Called By]

- >> LED_CUBE_Animation_Cube_2_auto

LED_CUBE_Animations_Cube2_move_z_fwd (Thumb, 36 bytes, Stack size 16 bytes, led_cube_8x8x8_animations.o(.text), UNUSED)

[Called By]

- >> LED_CUBE_Animation_Cube_2_auto

LED_CUBE_Animations_Cube2_move_x_rev (Thumb, 40 bytes, Stack size 12 bytes, led_cube_8x8x8_animations.o(.text), UNUSED)

[Called By]

- >> LED_CUBE_Animation_Cube_2_auto

LED_CUBE_Animations_Cube2_move_x_fwd (Thumb, 36 bytes, Stack size 12 bytes, led_cube_8x8x8_animations.o(.text), UNUSED)

[Called By]

- >> LED_CUBE_Animation_Cube_2_auto

LED_CUBE_Animations_Cube2_move_y_rev (Thumb, 40 bytes, Stack size 12 bytes, led_cube_8x8x8_animations.o(.text), UNUSED)

[Called By]

- >> LED_CUBE_Animation_Cube_2_auto

LED_CUBE_Animations_Cube2_move_y_fwd (Thumb, 36 bytes, Stack size 12 bytes, led_cube_8x8x8_animations.o(.text), UNUSED)

[Called By]

- >> LED_CUBE_Animation_Cube_2_auto

LED_CUBE_Animation_Cube_2_auto (Thumb, 468 bytes, Stack size 48 bytes, led_cube_8x8x8_animations.o(.text), UNUSED)

[Calls]

- >> rand
- >> LED_CUBE_Animations_Cube2_move_y_fwd
- >> LED_CUBE_Animations_Cube2_move_y_rev
- >> LED_CUBE_Animations_Cube2_move_x_fwd
- >> LED_CUBE_Animations_Cube2_move_x_rev
- >> LED_CUBE_Animations_Cube2_move_z_fwd
- >> LED_CUBE_Animations_Cube2_move_z_rev
- >> LED_CUBE_Animations_Cube_2_auto_show
- >> LED_CUBE_Clear

LED_CUBE_Animations_Cubes_2 (Thumb, 400 bytes, Stack size 8 bytes, led_cube_8x8x8_animations.o(.text), UNUSED)

[Calls]

- >> move_z_fwd
- >> move_y_rev
- >> move_y_fwd
- >> move_x_fwd
- >> Delay_ms
- >> LED_CUBE_Clear

LED_CUBE_Animations_wipe (Thumb, 82 bytes, Stack size 24 bytes, led_cube_8x8x8_animations.o(.text))

[Stack]

- Max Depth = 60
- Call Chain = LED_CUBE_Animations_wipe ⇒ move_y_rev

[Calls]

- >> move_y_rev
- >> Delay_ms
- >> LED_CUBE_Test_y

[Called By]

- >> main

LED_CUBE_Animations_explosion (Thumb, 188 bytes, Stack size 32 bytes, led_cube_8x8x8_animations.o(.text), UNUSED)

[Calls]

- >> Delay_ms

LED_CUBE_Animations_Outline_shrink (Thumb, 202 bytes, Stack size 8 bytes, led_cube_8x8x8_animations.o(.text), UNUSED)

[Calls]

- >> Delay_ms
- >> LED_CUBE_Clear

LED_CUBE_Animations_Cubes_4 (Thumb, 382 bytes, Stack size 8 bytes, led_cube_8x8x8_animations.o(.text))

[Stack]

- Max Depth = 44
- Call Chain = LED_CUBE_Animations_Cubes_4 ⇒ move_y_rev

[Calls]

- >> move_z_rev
- >> move_z_fwd
- >> move_y_rev
- >> move_y_fwd
- >> move_x_rev
- >> move_x_fwd
- >> Delay_ms
- >> LED_CUBE_Clear

[Called By]

- >> main

LED_CUBE_Animations_Cube_stars (Thumb, 86 bytes, Stack size 32 bytes, led_cube_8x8x8_animations.o(.text), UNUSED)

[Calls]

- >> rand
- >> Delay_ms
- >> LED_CUBE_Clear

LED_CUBE_Animations_Cube_Outline (Thumb, 256 bytes, Stack size 16 bytes, led_cube_8x8x8_animations.o(.text), UNUSED)

[Calls]

- >> rotate_90_auto
- >> Delay_ms
- >> LED_CUBE_Clear

LED_CUBE_Animations_Cube_waves (Thumb, 436 bytes, Stack size 16 bytes, led_cube_8x8x8_animations.o(.text))

[Stack]

- Max Depth = 48
- Call Chain = LED_CUBE_Animations_Cube_waves ⇒ move_x_rev

[Calls]

- >> move_x_rev
- >> Delay_ms
- >> LED_CUBE_Clear

[Called By]

- >> main

LED_CUBE_Animations_Cube_sonic (Thumb, 936 bytes, Stack size 40 bytes, led_cube_8x8x8_animations.o(.text), UNUSED)

[Calls]

- >> rand
- >> rotate_90_deg
- >> Delay_ms
- >> LED_CUBE_Clear

LED_CUBE_Animtions_Outline_shrink (Thumb, 196 bytes, Stack size 8 bytes, led_cube_8x8x8_animations.o(.text), UNUSED)

[Calls]

- >> Delay_ms
- >> LED_CUBE_Clear

LED_CUBE_Animations_Show_belt (Thumb, 154 bytes, Stack size 24 bytes, led_cube_8x8x8_animations.o(.text), UNUSED)

[Calls]

- >> Delay_ms
- >> LED_CUBE_Clear

invaders_move_right (Thumb, 250 bytes, Stack size 32 bytes, led_cube_8x8x8_animations.o(.text), UNUSED)

[Called By]

- >> invader_show_loop

invaders_move_left (Thumb, 252 bytes, Stack size 32 bytes, led_cube_8x8x8_animations.o(.text), UNUSED)

[Called By]

- >> invader_show_loop

invaders_move_down (Thumb, 158 bytes, Stack size 16 bytes, led_cube_8x8x8_animations.o(.text), UNUSED)

[Called By]

- >> invader_show_loop

LED_CUBE_Animations_Cube_invaders (Thumb, 340 bytes, Stack size 32 bytes, led_cube_8x8x8_animations.o(.text), UNUSED)

[Calls]

- >> rand
- >> move_z_rev
- >> move_z_fwd
- >> move_x_rev
- >> move_x_fwd
- >> Delay_ms
- >> invader_show_loop
- >> LED_CUBE_Clear

LED_CUBE_Animations_Cube_belt_wipe (Thumb, 90 bytes, Stack size 16 bytes, led_cube_8x8x8_animations.o(.text), UNUSED)

[Calls]

- >> Delay_ms

LED_CUBE_Animations_Cube_block_wipe (Thumb, 100 bytes, Stack size 16 bytes, led_cube_8x8x8_animations.o(.text), UNUSED)

[Calls]

- >> move_x_fwd
- >> Delay_ms

LED_CUBE_Animations_Cube_stripes (Thumb, 206 bytes, Stack size 24 bytes, led_cube_8x8x8_animations.o(.text), UNUSED)

[Calls]

- >> Delay_ms
- >> LED_CUBE_Clear

move_z_fwd (Thumb, 36 bytes, Stack size 20 bytes, led_cube_8x8x8_translation.o(.text))

[Stack]

- Max Depth = 20
- Call Chain = move_z_fwd

[Called By]
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

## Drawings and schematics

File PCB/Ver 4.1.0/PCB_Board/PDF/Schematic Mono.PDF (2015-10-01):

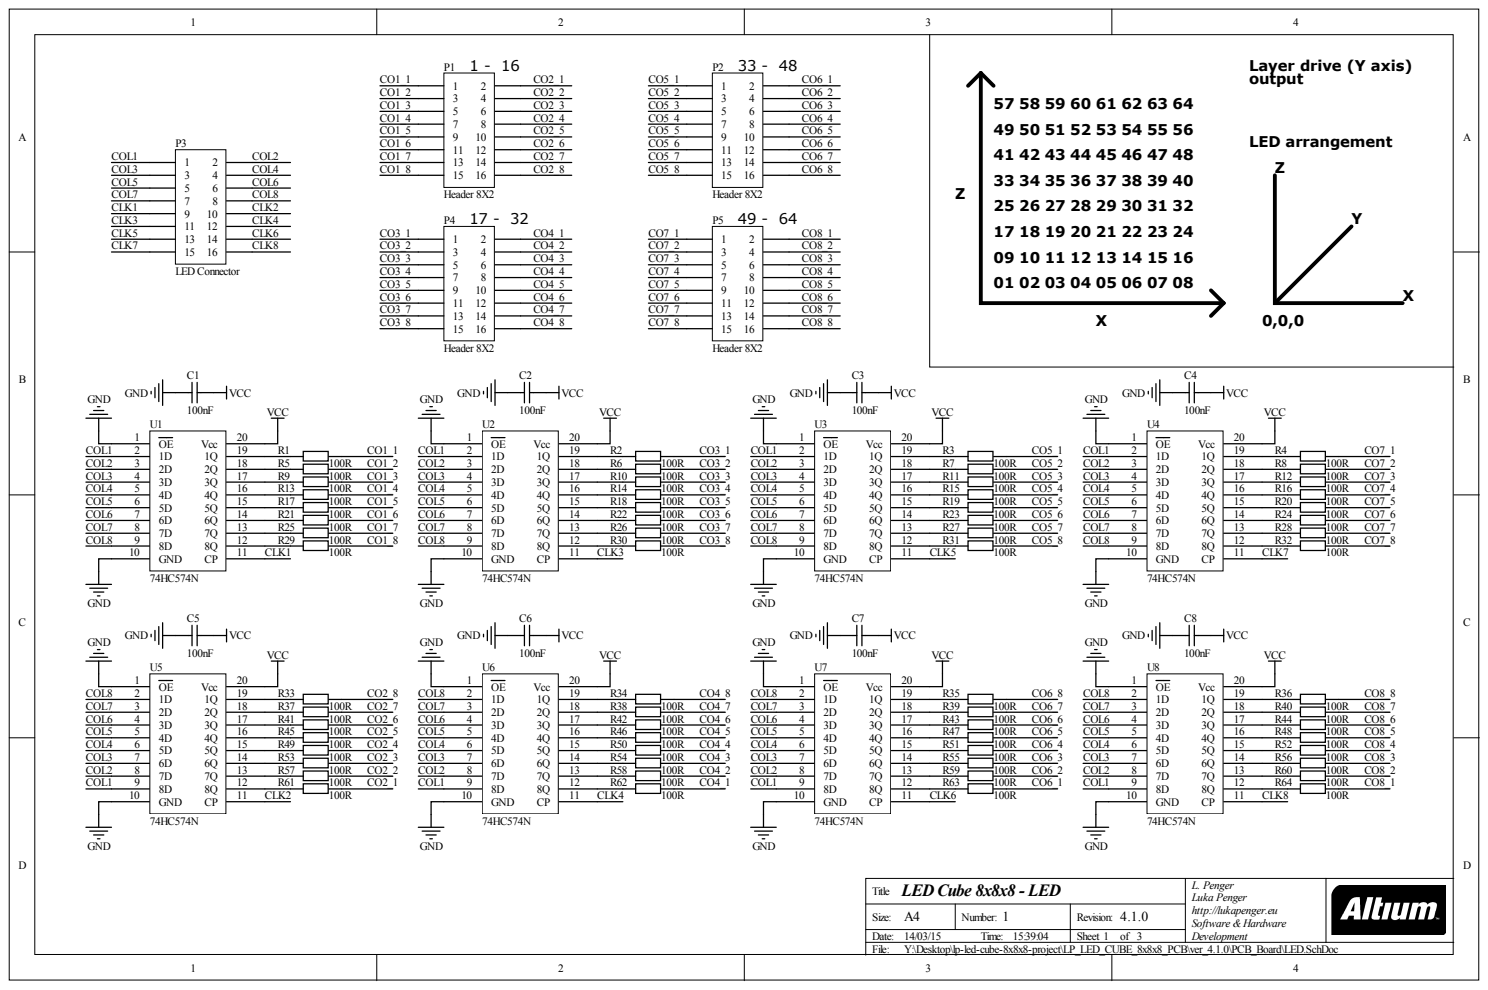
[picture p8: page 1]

Title LED Cube 8x8x8 - LED | L. Penger Luka Penger http://lukapenger.eu Software & Hardware Development

Size: A4 | Number: 1 | Revision: 4.1.0

1 2 | Date: 14/03/15 Time: 15:39:04 Sheet 1 of 3 File: Y:\Desktop\lp-led-cube-8x8x8-project\LP_LED_CUBE_8x8x8_PCB\ver_4.1.0\PCB_Board\LED.SchDoc 3 4

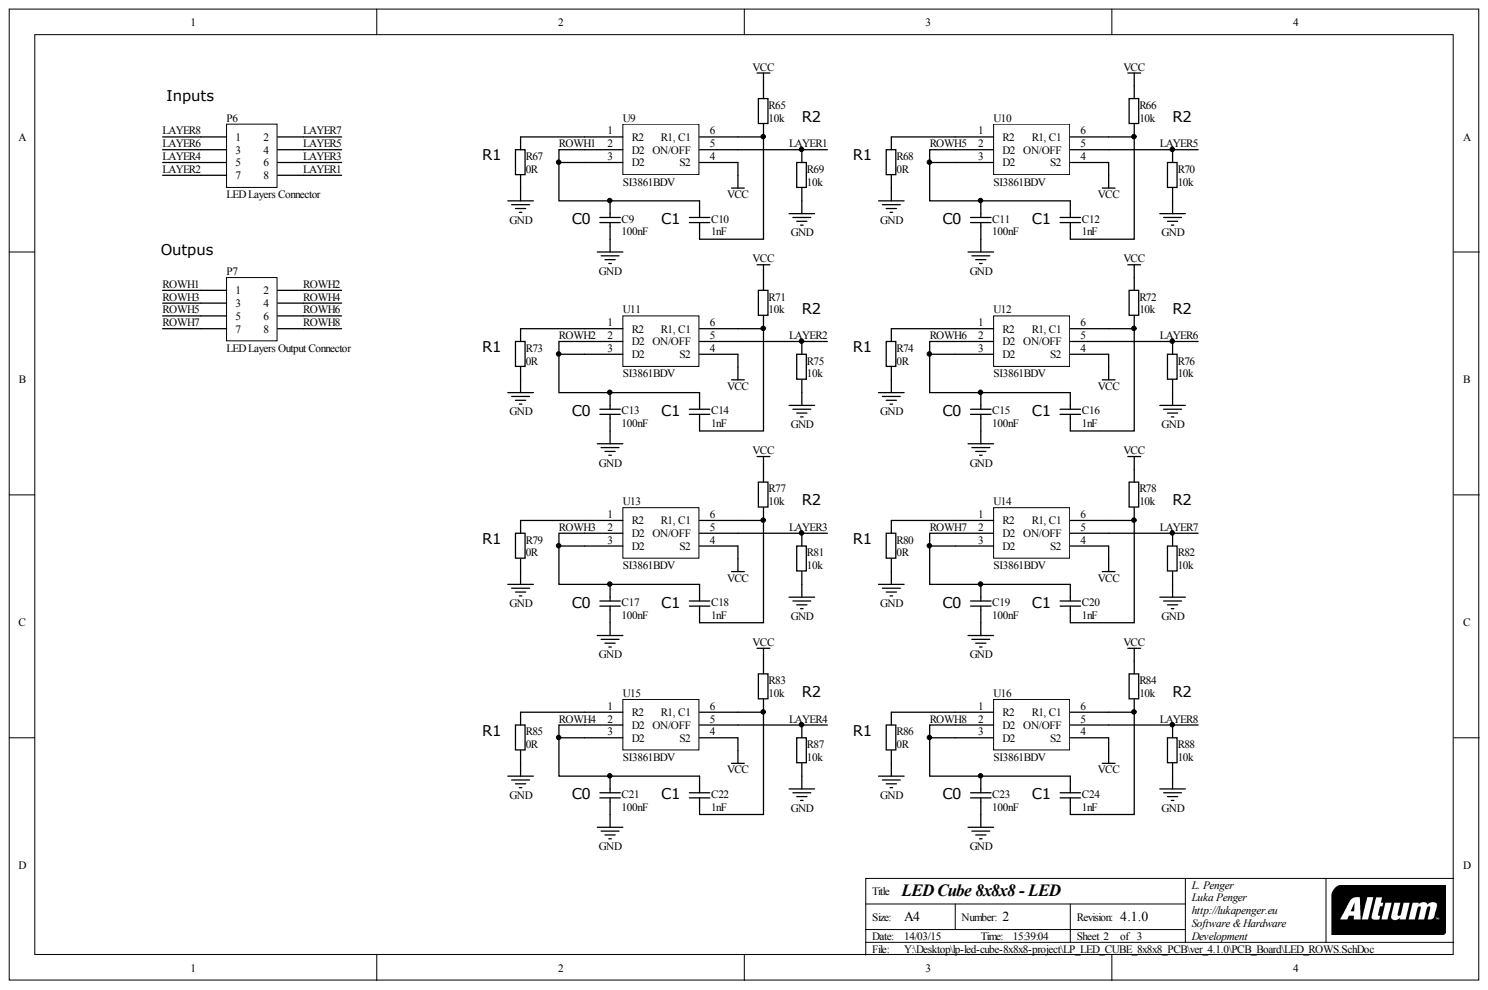
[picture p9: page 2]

: A4 | Numb er : 2 | Re vis io n: 4.1.0
Date : 1 4 /0 3 / 1 5 Time : 1 5 : 3 9 : 0 4 F ile : Y :\D e s ktop \lp -le d -cub e -8 x8 x8 -p roj e c t\LP | S he e t 2 o f 3 _LED_C UBE_ 8 x8 x8 _P C | B\ver_4 . 1 . 0 \P C B_B o ard\LED_RO | W S . S c hDo c

LED Cub e 8x8x8 -LED | L L . u Penge k a P enge r r h t tp : //lu k ap enge r. e u Soft w a re & Ha rdw a re De v e lop m e n t

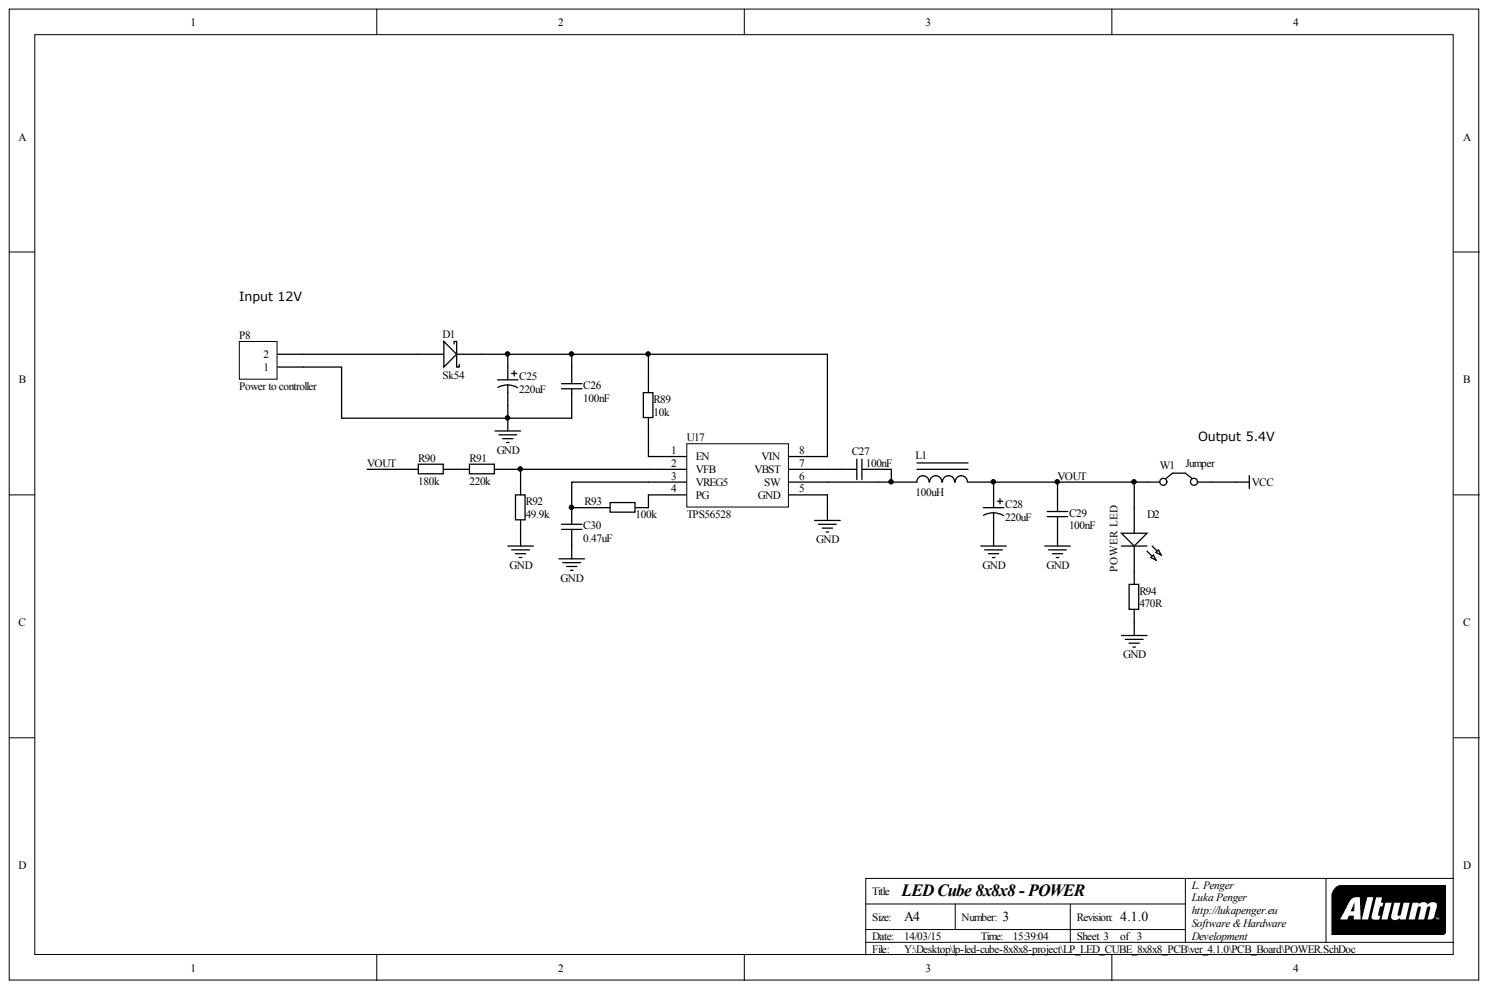
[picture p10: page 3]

: A4 | Numb er : 3 | Re vis io n: 4.1.0
Date : 1 4 /0 3 / 1 5 Time : 1 5 : 3 9 : 0 4 F ile : Y :\D e s ktop \lp -le d -cub e -8 x8 x8 -p roj e c t\LP | S he e t 3 o f 3 _LED_C UBE_ 8 x8 x8 _P C | B\ver_4 . 1 . 0 \P C B_B o ard\P O WER. | S c hDo c

LED Cub e 8x8x8 -PO WER | L L . u Penge k a P enge r r h t tp : //lu k ap enge r. e u Soft w a re & Ha rdw a re De v e lop m e n t

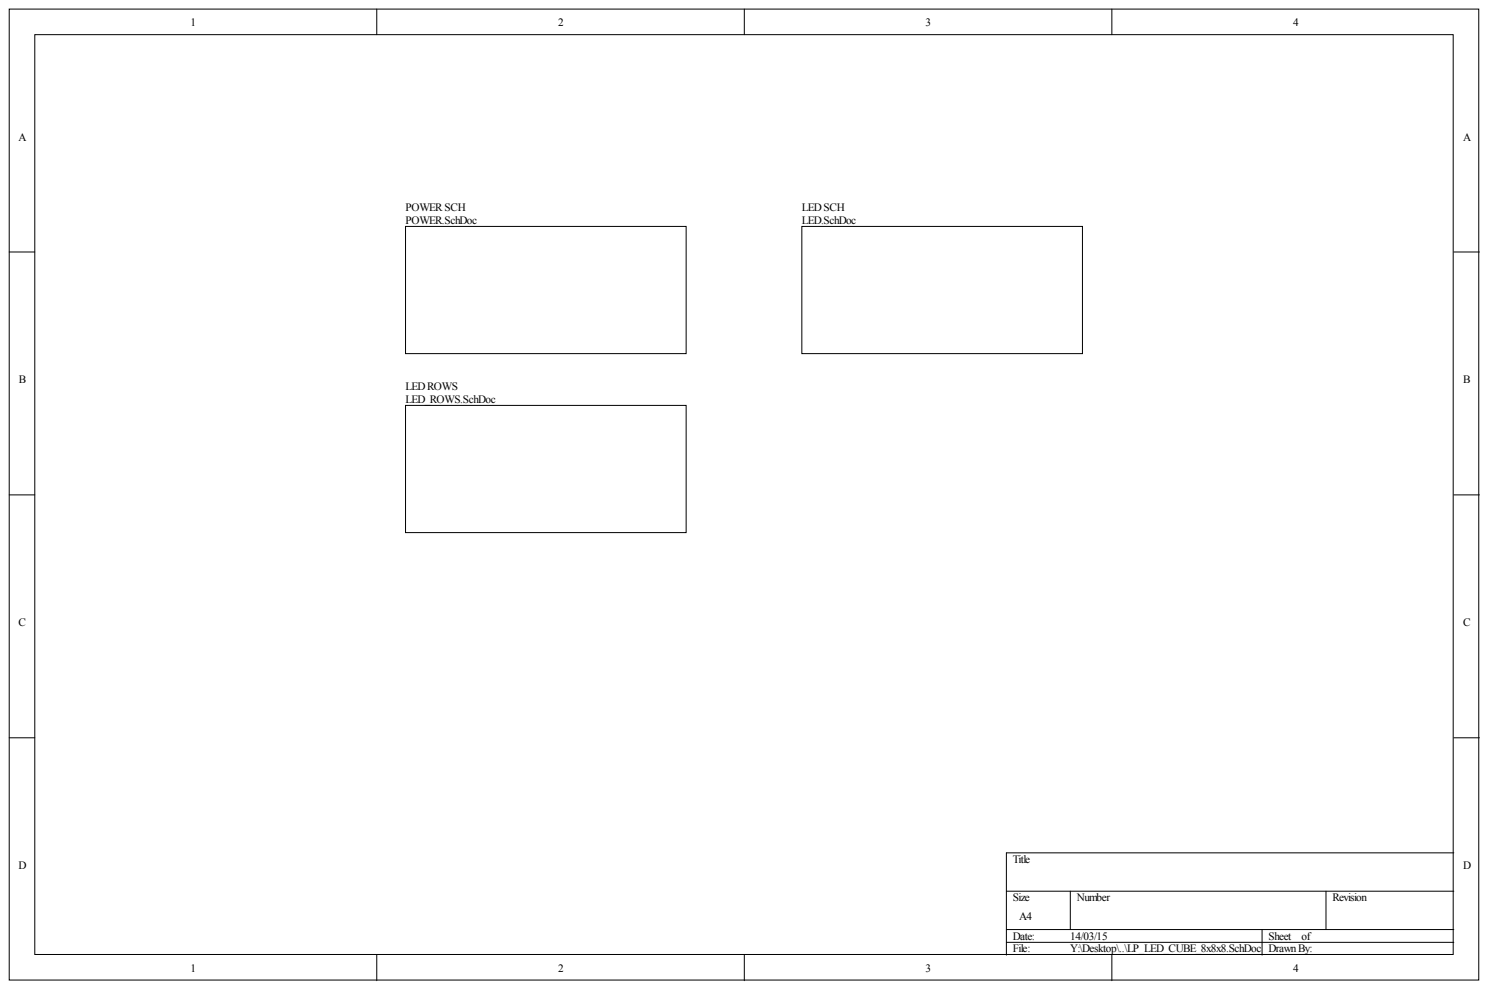
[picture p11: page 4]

Size A4 | Number | Revision

1 2 3 | Date: 14/03/15 File: Y:\Desktop\..\LP_LED_CUBE_8x8x8.SchDoc | Sheet of DrawnBy: 4

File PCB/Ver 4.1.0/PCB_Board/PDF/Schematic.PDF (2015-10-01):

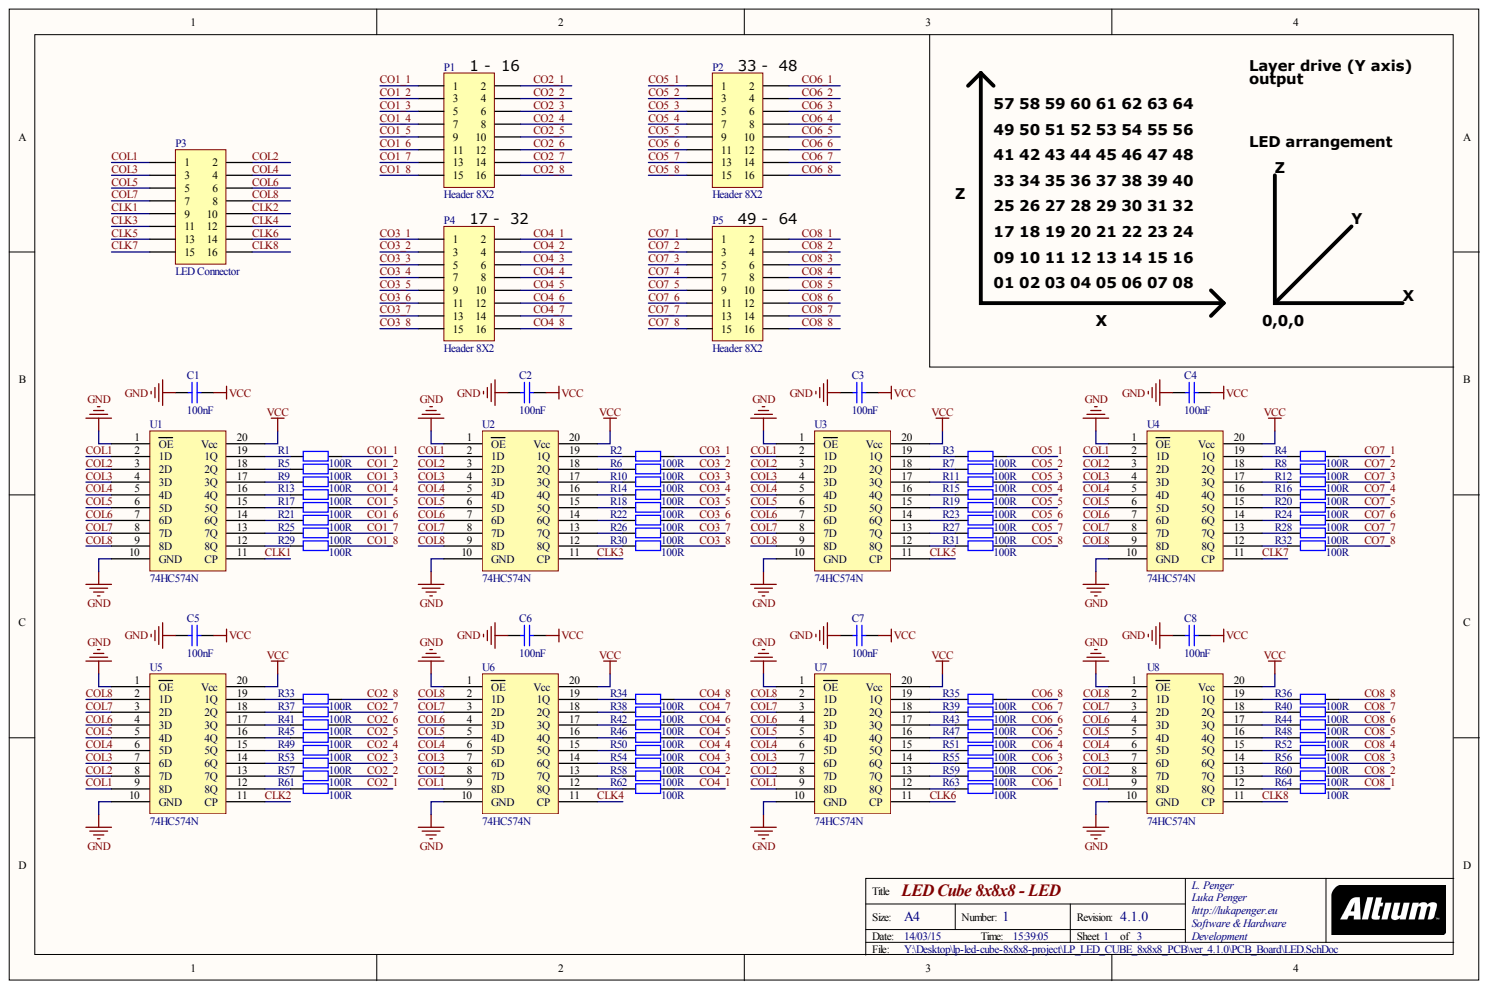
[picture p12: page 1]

Title LED Cube 8x8x8 - LED | L. Penger Luka Penger http://lukapenger.eu Software & Hardware Development

Size: A4 | Number: 1 | Revision: 4.1.0

1 2 | Date: 14/03/15 Time: 15:39:05 Sheet 1 of 3 File: Y:\Desktop\lp-led-cube-8x8x8-project\LP_LED_CUBE_8x8x8_PCB\ver_4.1.0\PCB_Board\LED.SchDoc 3 4

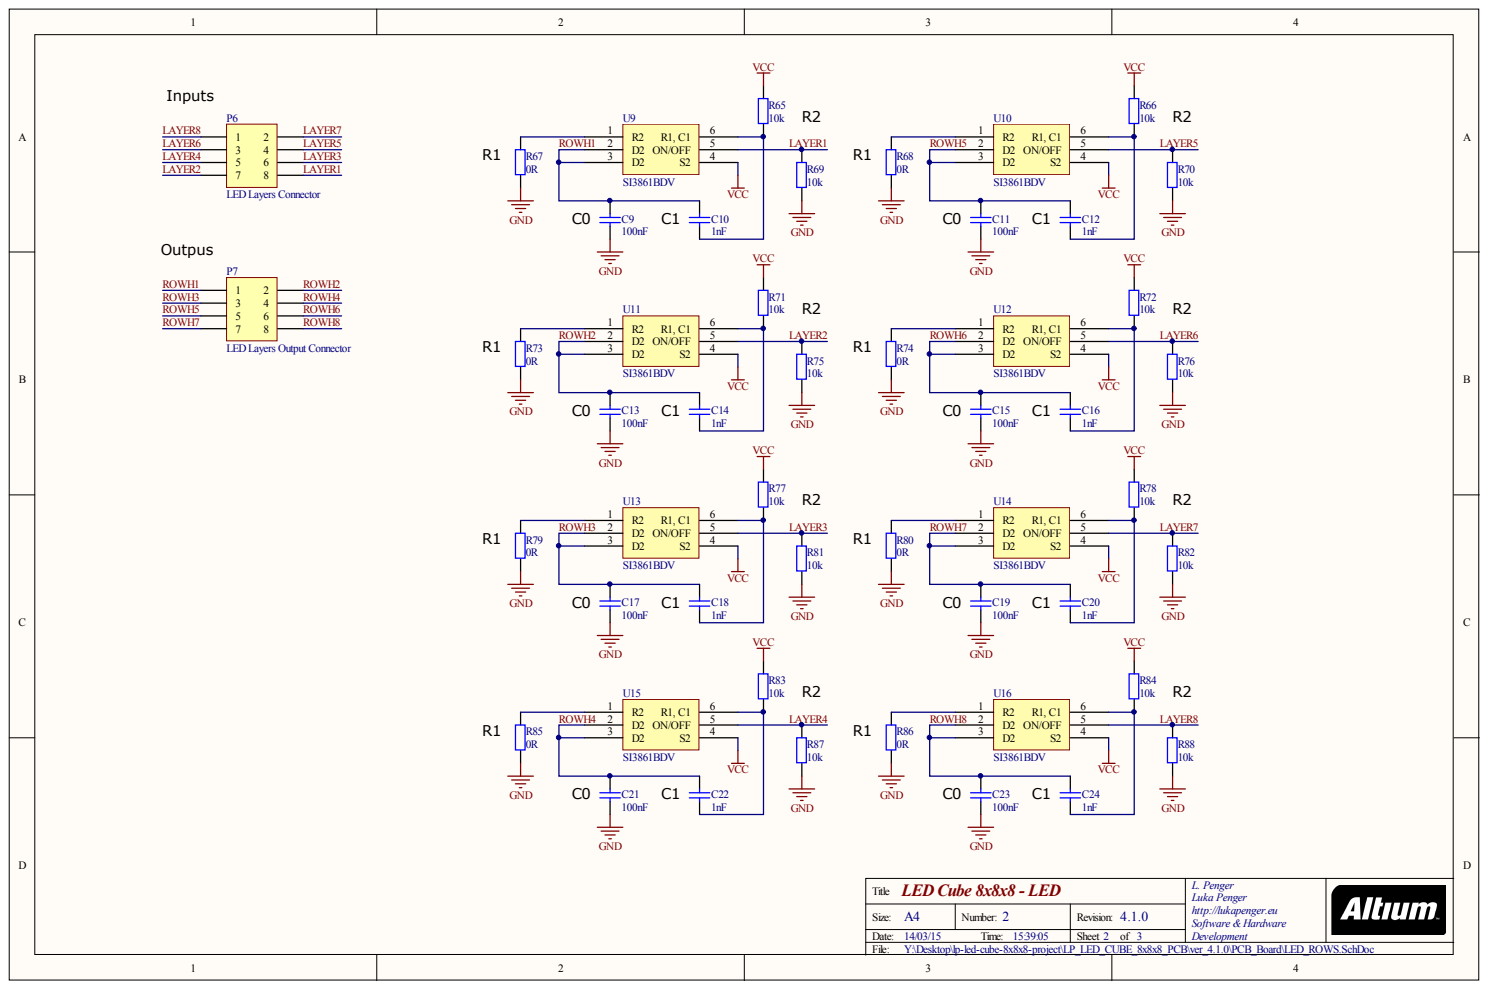
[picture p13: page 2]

: A4 | Numb er : 2 | Re vis io n: 4.1.0
Date : 1 4 /0 3 / 1 5 Time : 1 5 : 3 9 : 0 5 F ile : Y :\D e s ktop \lp -le d -cub e -8 x8 x8 -p roj e c t\LP | S he e t 2 o f 3 _LED_C UBE_ 8 x8 x8 _P C | B\ver_4 . 1 . 0 \P C B_B o ard\LED_RO | W S . S c hDo c

LED Cub e 8x8x8 -LED | L L . u Penge k a P enge r r h t tp : //lu k ap enge r. e u Soft w a re & Ha rdw a re De v e lop m e n t

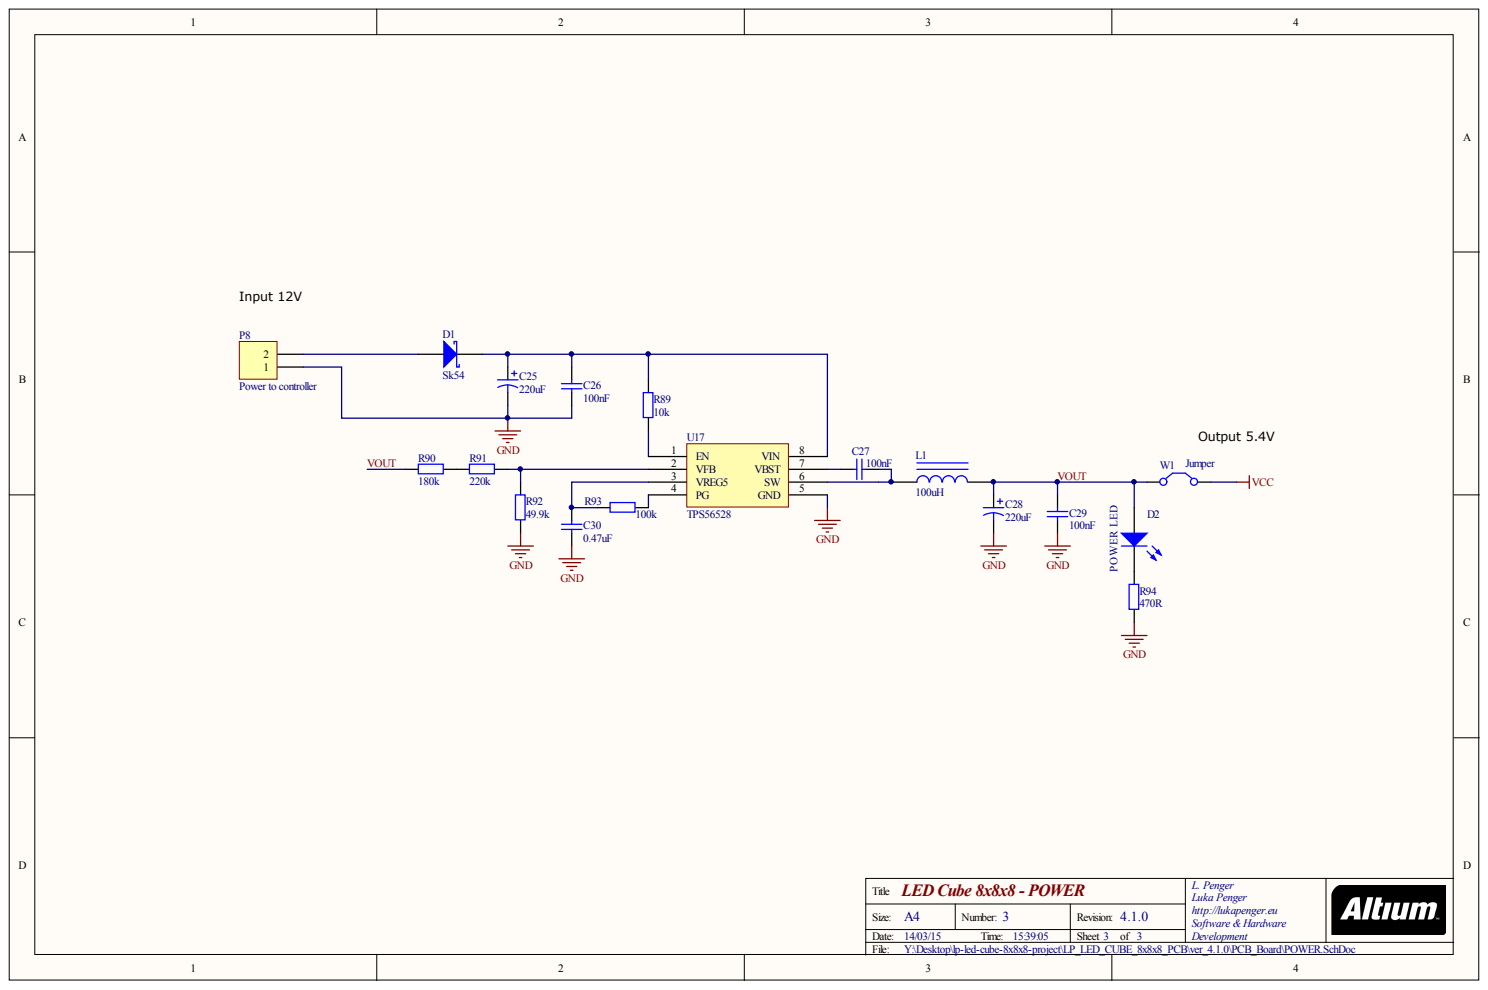
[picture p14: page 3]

: A4 | Numb er : 3 | Re vis io n: 4.1.0
Date : 1 4 /0 3 / 1 5 Time : 1 5 : 3 9 : 0 5 F ile : Y :\D e s ktop \lp -le d -cub e -8 x8 x8 -p roj e c t\LP | S he e t 3 o f 3 _LED_C UBE_ 8 x8 x8 _P C | B\ver_4 . 1 . 0 \P C B_B o ard\P O WER. | S c hDo c

LED Cub e 8x8x8 -PO WER | L L . u Penge k a P enge r r h t tp : //lu k ap enge r. e u Soft w a re & Ha rdw a re De v e lop m e n t

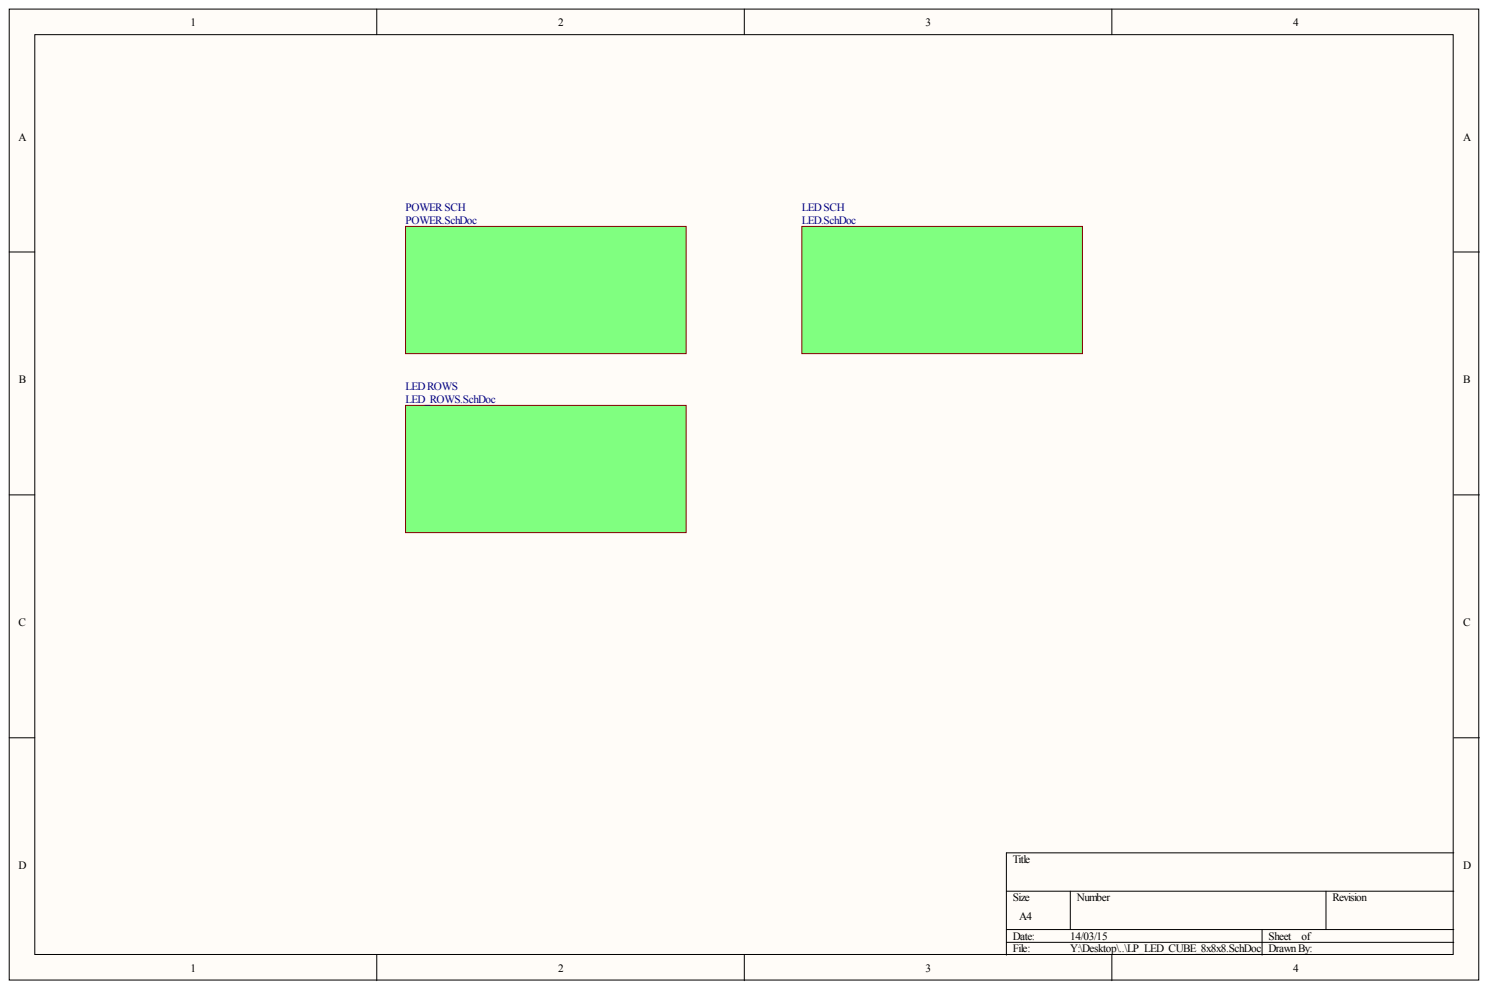
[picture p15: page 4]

Size A4 | Number | Revision

1 2 3 | Date: 14/03/15 File: Y:\Desktop\..\LP_LED_CUBE_8x8x8.SchDoc | Sheet of DrawnBy: 4

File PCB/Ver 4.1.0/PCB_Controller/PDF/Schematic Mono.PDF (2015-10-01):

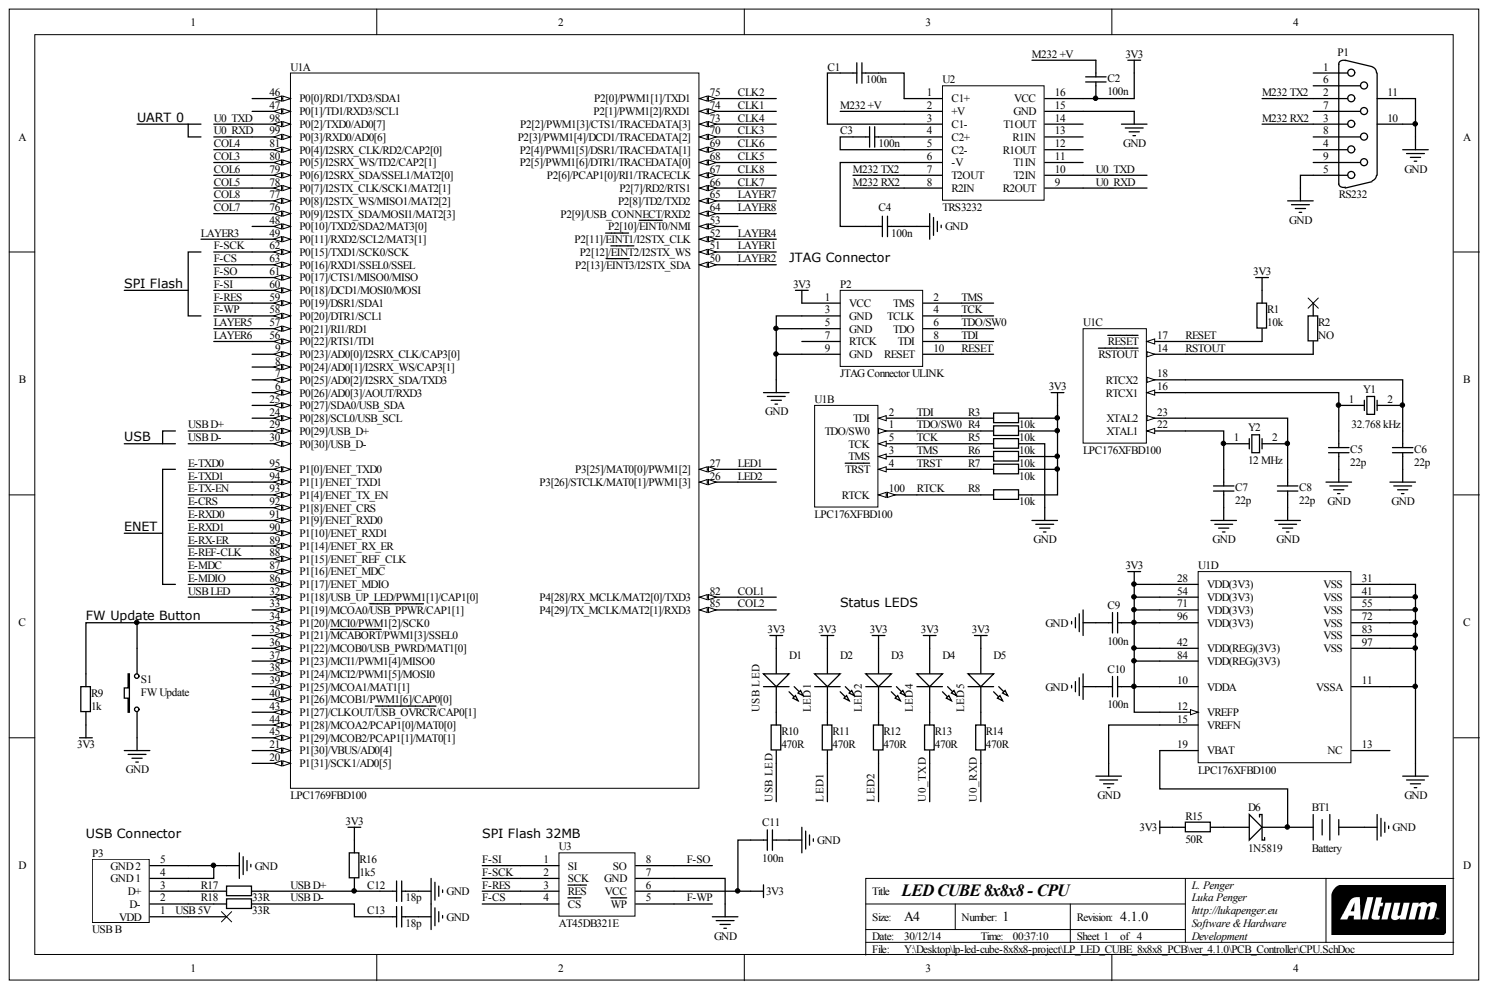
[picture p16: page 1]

LED CUBE 8x8x8 - CPU
Title
Date:
Y:\Desktop\lp-led-cube-8x8x8-project\LP_LED_CUBE_8x8x8_PCB\ver_4.1.0\PCB_Controller\CPU.SchDoc
File:

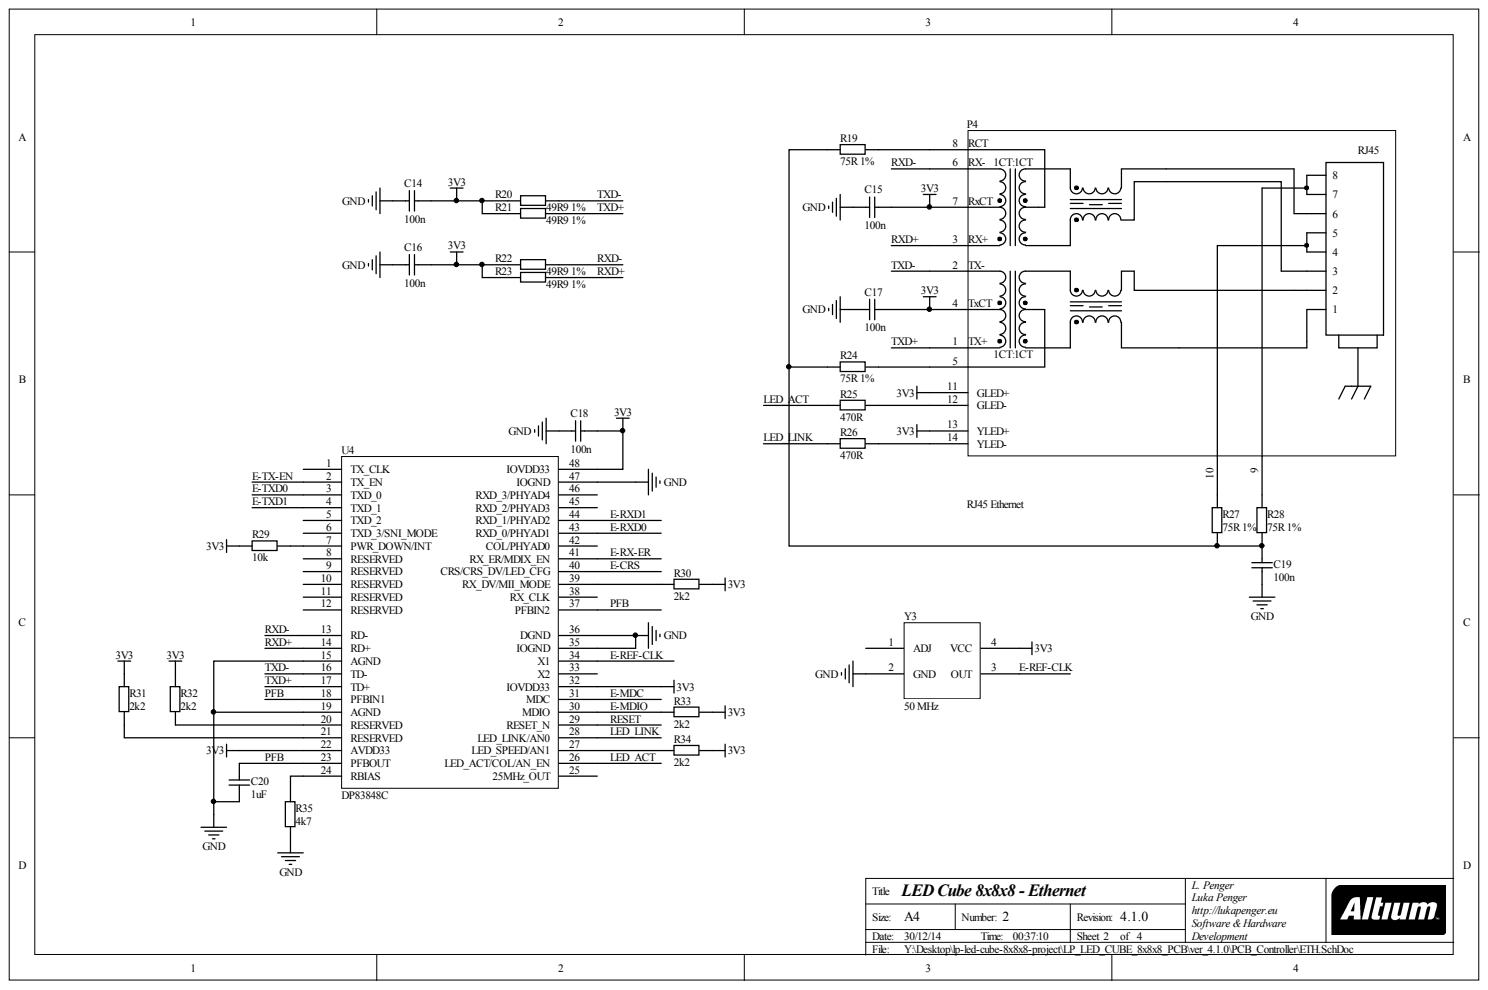
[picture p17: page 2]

GND | 75R1% RXD-6 100n 100n R24 | 1CT:1CT RxCT | 8 7 6 5 4 3 2 1

RESERVED 20 | E-MDIO RESET

RESERVED 21 AVDD33 22 PFBOUT 23 | LED_LINK LED_ACT

Title LED Cube 8x8x8 - Ethernet | L. Penger Luka Penger http://lukapenger.eu Software & Hardware Development

Size: A4 | Number: 2 | Revision: 4.1.0

1 2 | Date: 30/12/14 Time: 00:37:10 Sheet 2 of 4 File: Y:\Desktop\lp-led-cube-8x8x8-project\LP_LED_CUBE_8x8x8_PCB\ver_4.1.0\PCB_Controller\ETH.SchDoc 3 4

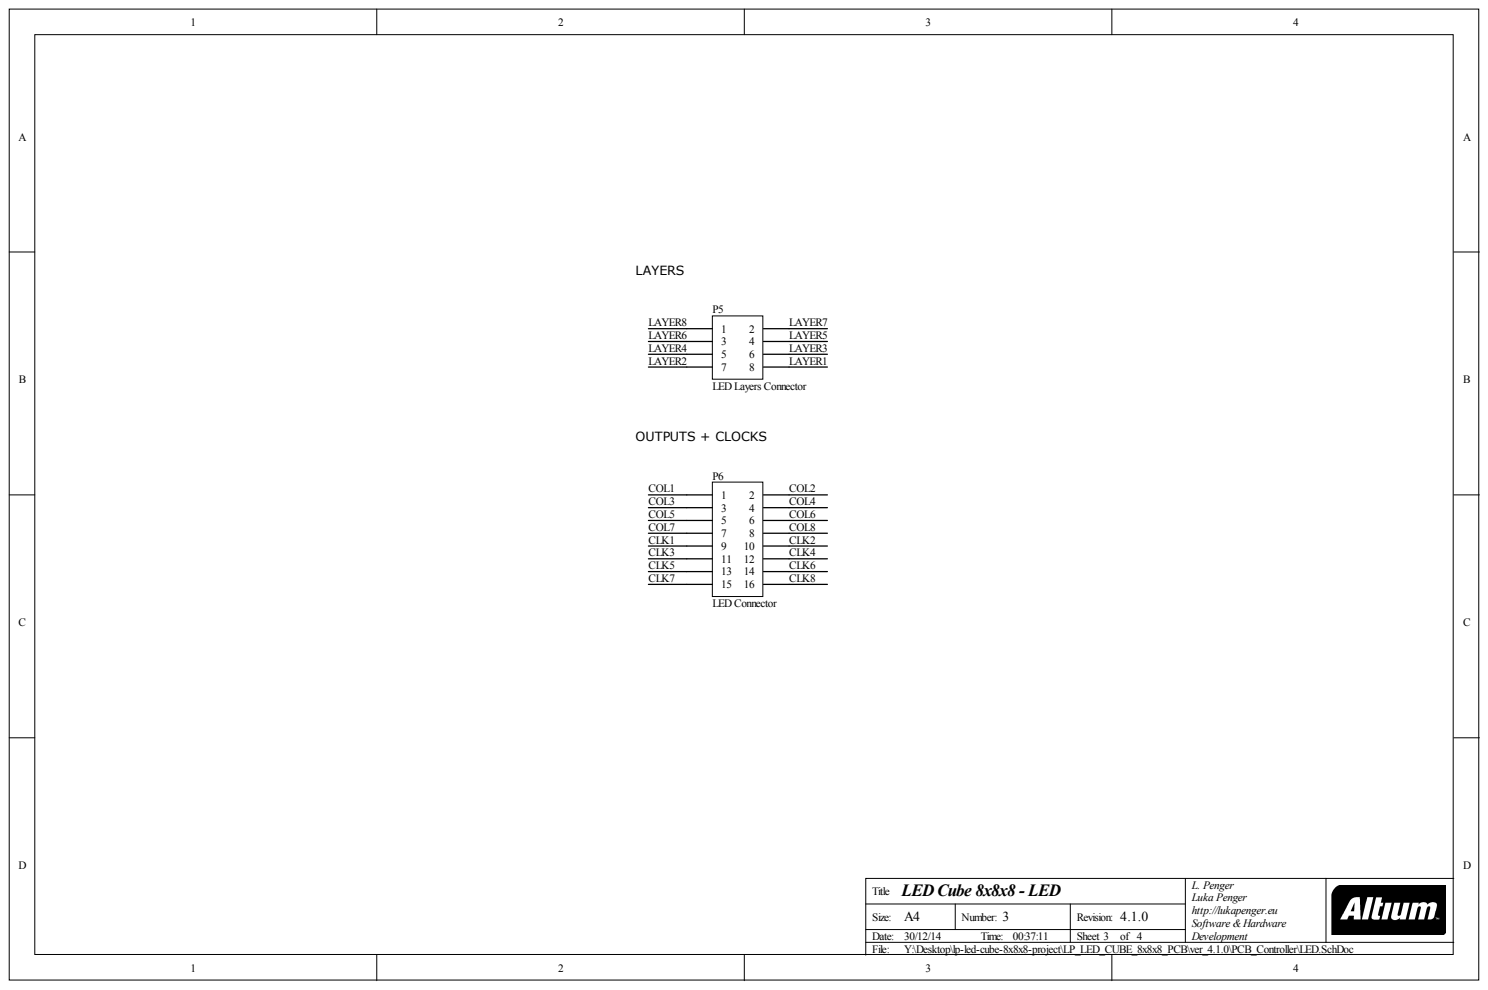
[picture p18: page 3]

Title LED Cube 8x8x8 - LED | L. Penger Luka Penger http://lukapenger.eu Software & Hardware Development

Size: A4 | Number: 3 | Revision: 4.1.0

1 2 | Date: 30/12/14 Time: 00:37:11 Sheet 3 of 4 File: Y:\Desktop\lp-led-cube-8x8x8-project\LP_LED_CUBE_8x8x8_PCB\ver_4.1.0\PCB_Controller\LED.SchDoc 3 4

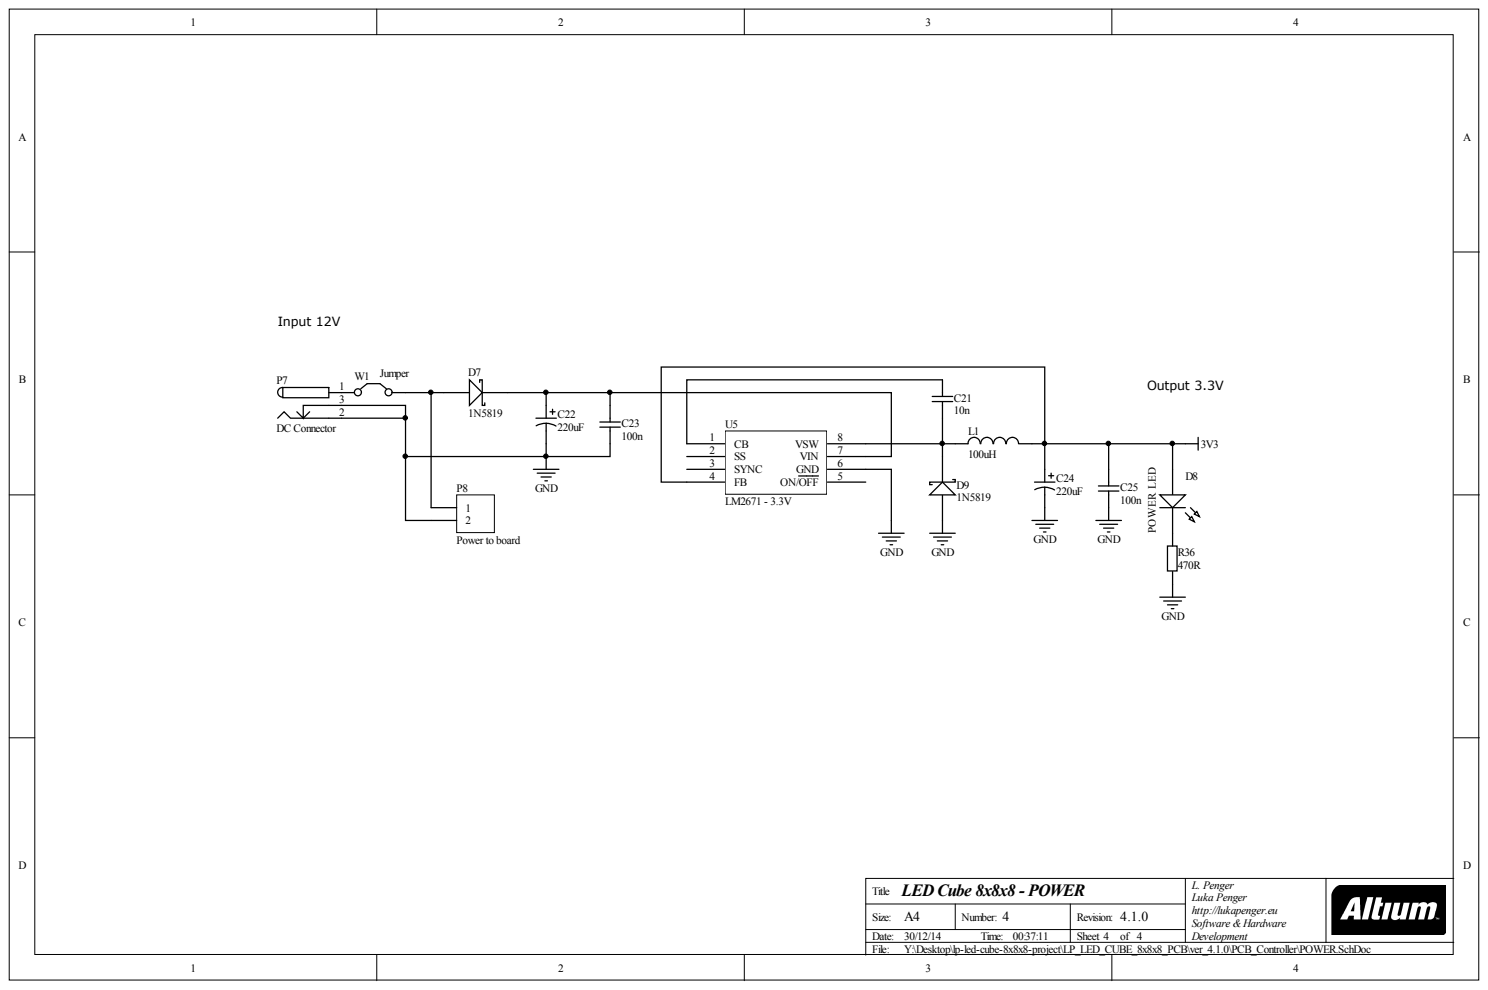
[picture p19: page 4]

: A4 | Numb er : 4 | Re vis io n: 4.1.0
Date : 3 0 / 1 2 / 1 4 Time : 0 0 : 3 7 : 1 1 F ile : Y :\D e s ktop \lp -le d -cub e -8 x8 x8 -p roj e c t\LP | S he e t 4 o f 4 _LED_C UBE_ 8 x8 x8 _P C | B\ver_4 . 1 . 0 \P C B_C o ntro ller\P O | WER. S c hDo c

LED Cub e 8x8x8 -PO WER | L L . u Penge k a P enge r r h t tp : //lu k ap enge r. e u Soft w a re & Ha rdw a re De v e lop m e n t


Size A4 | Number | Revision

1 2 3 | Date: 30/12/14 File: Y:\Desktop\..\LP_LED_CUBE_8x8x8.SchDoc | Sheet of DrawnBy: 4

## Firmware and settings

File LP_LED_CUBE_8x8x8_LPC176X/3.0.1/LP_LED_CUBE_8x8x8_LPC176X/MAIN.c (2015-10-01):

/*----------------------------------------------------------------------------
 *      LED CUBE 8x8x8
 *			Copyright 2014
 *			Luka Penger
 *			LPProjects
 *			http://lpprojects.eu
 *---------------------------------------------------------------------------*/

#include <stdio.h>
#include <RTL.h>
#include <Net_Config.h>
#include <LPC17xx.H>
#include <string.h>
#include <stdlib.h>
#include <DELAY.h>
#include <rl_usb.h>
#include <LED_CUBE_8x8x8.h>
#include <UART.h>
#include <PROTOCOL.h>
#include <TCP_USERS.h>
#include <RTC.h>
#include <SNTP.h>
#include <SETTINGS.h>
#include <ADMINS.h>
#include <USERS.h>

/*--------------------------- device configuration --------------------------*/

#define STATUS_LED1_PIN													25
#define STATUS_LED2_PIN													26

#define UART_CONSOLE_NUMBER											0
#define UART_CONSOLE_BAUD_RATE									115200

#define UDP_PORT																10023
#define TCP_PORT																10023

/*---------------------------------------------------------------------------*/

char *AnimationFileName;
BOOL ANIMATION_PLAY = FALSE;
int AnimationFileSize = 0;
int AnimationEffectsCount = 0;
int CurrentAnimationEffect = 0;
LED_CUBE_Effect currentEffect;

char DelayValue = 0;

U8 UDP_Socket;
U8 TCP_Socket;

BOOL TICK_10MS;
BOOL TICK_100MS;
BOOL DHCP_TICK;
BOOL DHCP_SUCCESS;

extern struct http_cfg http_config;
#define HTTP_ADMIN_PASSWORD http_config.Passw

extern LOCALM localm[];                       /* Local Machine Settings */
#define DEVICE_IP localm[NETIF_ETH].IpAdr
#define DEVICE_SUBNETMASK localm[NETIF_ETH].NetMask
#define DEVICE_GATEWAY localm[NETIF_ETH].DefGW
#define DEVICE_PriDNS localm[NETIF_ETH].PriDNS
#define DEVICE_SecDNS localm[NETIF_ETH].SecDNS

/*--------------------------- TCP USER SESSIONS ---------------------------------*/

extern TCP_USER_INFO TCP_USER_SESSIONS[TCP_USER_NUMBER_OF_SESSIONS];
extern char TCP_Buffer_Send[TCP_BUFFER_SEND_SIZE];
extern int TCP_Buffer_Send_Length;

/*--------------------------- SETTINGS --------------------------------------*/

extern char *SETTINGS_DATA[SETTINGS_STRINGS_NUMBER];

/*--------------------------- USERS -----------------------------------------*/

extern USER Users[MAX_NUMBER_OF_USERS];
extern int USERS_Count(void);

/*--------------------------- ADMINS ----------------------------------------*/

extern ADMIN Admins[MAX_NUMBER_OF_ADMINS];
extern int ADMINS_Count(void);

/*--------------------------- flash -----------------------------------------*/

void SPI_FLASH_Format (void) {
	fformat("S:");
}

void SPI_FLASH_Delete_All_Files (void) {
	FINFO file_info;
	file_info.fileID = 0;
	
	while(ffind("*.*", &file_info) == 0) {
		fdelete((const char*)file_info.name); 
	}
}

/*--------------------------- uart console ----------------------------------*/

extern volatile unsigned int UART_Status[2];
extern volatile unsigned char UART_TxEmpty[2];
extern volatile unsigned char UART_Buffer[2][UART_BUFSIZE];
extern volatile unsigned int UART_Count[2];

void UART_CONSOLE_Init (void) {
	UART_Init(UART_CONSOLE_NUMBER, UART_CONSOLE_BAUD_RATE);
}

void UART_CONSOLE_Send_Buffer (char *buffer, unsigned int length) {
	UART_SendBuffer(UART_CONSOLE_NUMBER, buffer, length);
}

void UART_CONSOLE_Send_String (char *string) {
	UART_SendBuffer(UART_CONSOLE_NUMBER, string, strlen(string));
}

void UART_CONSOLE_Send_Char (char value) {
	UART_SendChar(UART_CONSOLE_NUMBER, value);
}

/*--------------------------- status leds -----------------------------------*/

void Status_LEDs_Init (void) {
	LPC_GPIO3->FIODIR |= (1<<STATUS_LED1_PIN);
	LPC_GPIO3->FIODIR |= (1<<STATUS_LED2_PIN);
	
	LPC_GPIO3->FIOSET |= (1<<STATUS_LED1_PIN);
	LPC_GPIO3->FIOSET |= (1<<STATUS_LED2_PIN);
}

void Status_LED1_Set (BOOL state) {
	if (state) {
		LPC_GPIO3->FIOCLR |= (1<<STATUS_LED1_PIN);
	} else {
		LPC_GPIO3->FIOSET |= (1<<STATUS_LED1_PIN);
	}
}

void Status_LED2_Set (BOOL state) {
	if (state) {
		LPC_GPIO3->FIOCLR |= (1<<STATUS_LED2_PIN);
	} else {
		LPC_GPIO3->FIOSET |= (1<<STATUS_LED2_PIN);
	}
}

void Status_LED1_Toggle (void) {
	Status_LED1_Set((LPC_GPIO3->FIOPIN & (1<<STATUS_LED1_PIN)));
}

void Status_LED2_Toggle (void) {
	Status_LED2_Set((LPC_GPIO3->FIOPIN & (1<<STATUS_LED2_PIN)));
}

/*--------------------------- udp socket ------------------------------------*/

U8 UDP_Socket;

char UDP_Socket_Buffer_Send[100];
char UDP_Socket_Buffer_Receive[100];
int UDP_Socket_Receive_Length = 0;
int UDP_Socket_Send_Length = 0;
BOOL UDP_Socket_Listener_Data_Received = FALSE;
char UDP_Socket_Remote_IP[4];

void UDP_Socket_Send (char udp_msg[], int len, char remip[])
{
	U8 *sendbuf;
	sendbuf = udp_get_buf (len);
	memcpy(sendbuf,udp_msg,len);
	udp_send(UDP_Socket, (U8 *)remip, UDP_PORT, sendbuf, len);
}

U16 UDP_Socket_Listener (U8 socket, U8 *remip, U16 port, U8 *buffer, U16 len)
{
	if (len <= sizeof(UDP_Socket_Buffer_Receive))
	{
		memcpy(UDP_Socket_Remote_IP, remip, 4); // Save remote ip
		memcpy(UDP_Socket_Buffer_Receive, buffer, len);
		UDP_Socket_Receive_Length = len;
		UDP_Socket_Listener_Data_Received = TRUE;
	}
	
  return TRUE;
}

void UDP_Socket_Init (void) {
	UDP_Socket = udp_get_socket(0, UDP_OPT_SEND_CS | UDP_OPT_CHK_CS, UDP_Socket_Listener);
	udp_open(UDP_Socket, UDP_PORT);
}

/*--------------------------- timer_poll ------------------------------------*/
char timer10s_tick = 0;

void timer_poll (void) {
  /* System tick timer running in poll mode */

  if (SysTick->CTRL & 0x10000) {
    /* Timer tick every 10 ms */
    timer_tick();
		
    DHCP_TICK = __TRUE;
		TICK_10MS = __TRUE;
		
		if (timer10s_tick >= 10) {
			timer10s_tick = 0;
			TICK_100MS = __TRUE;
		} else {
			timer10s_tick++;
		}
  }
}

/*--------------------------- dhcp_check ------------------------------------*/

void DHCP_Check (void) {
  /* Monitor DHCP IP address assignment. */

	if (DHCP_TICK == __TRUE) {
		DHCP_TICK = __FALSE;

		if (mem_test(&DEVICE_IP, 0, IP_ADRLEN) == __FALSE && DHCP_SUCCESS == __FALSE) {
			/* Success, DHCP has already got the IP address. */
			DHCP_SUCCESS = __TRUE;
			return;
		}
	}
}

/*--------------------------- animation -------------------------------------*/

void Animation_Read_Effect (void) {
	FILE *file;

	if (CurrentAnimationEffect <= AnimationEffectsCount) {
		file = fopen(AnimationFileName,"r");
		
		if (file != NULL) {
			fseek(file, (sizeof(LED_CUBE_Effect) * CurrentAnimationEffect), SEEK_SET);
			fread(&currentEffect, 1, sizeof(LED_CUBE_Effect), file);
			
			LED_CUBE_Rows_Set(currentEffect.rows);
			LED_CUBE_Columns_Set(currentEffect.columns[0], currentEffect.columns[1], currentEffect.columns[2], currentEffect.columns[3], currentEffect.columns[4], currentEffect.columns[5], currentEffect.columns[6], currentEffect.columns[7]);
			
			fclose(file);
		}
	}
}

void Animation_Start (void) {
	FILE *file = fopen(AnimationFileName,"r");
	FINFO file_info;
	file_info.fileID = 0;

	CurrentAnimationEffect = 0;
	DelayValue = 0;
	
	if (file != NULL) {
			if (ffind(AnimationFileName, &file_info) == 0) {
				AnimationFileSize = file_info.size;

				if (AnimationFileSize >= sizeof(LED_CUBE_Effect)) {
					ANIMATION_PLAY = TRUE;
					
					AnimationEffectsCount = (AnimationFileSize / sizeof(LED_CUBE_Effect));
					
					Animation_Read_Effect();					
				} else {
					ANIMATION_PLAY = FALSE;
					AnimationFileName = "";
				}
			} else {
				ANIMATION_PLAY = FALSE;
				AnimationFileName = "";
			}

		fclose(file);
	} else {
		ANIMATION_PLAY = FALSE;
		AnimationFileName = "";
	}

	SETTINGS_Save();
}

void Animation_Stop (void) {
	AnimationFileName = "";
	ANIMATION_PLAY = FALSE;
	
	LED_CUBE_Rows_Set(0x00);
	LED_CUBE_Columns_Set(0x00, 0x00, 0x00, 0x00, 0x00, 0x00, 0x00, 0x00);
	
	SETTINGS_Save();
}

/*--------------------------- init ------------------------------------------*/

void Init (void) {
	SystemInit();

	// Setup and enable the SysTick timer for 10ms.
  SysTick->LOAD = (SystemCoreClock / 100) - 1;
  SysTick->CTRL = 0x05;
	
	// Initialize all enabled drives.
  finit(NULL);

	// Init TcpNet
  init_TcpNet();
	
	// UDP Init
	UDP_Socket_Init();
	
	// TCP Users Init
	TCP_Users_Init(TCP_PORT);
	
	// UART Init
	UART_CONSOLE_Init();
	
	// Real time clock init
	RTC_Init();
	
	RTC_Start();

	// Load settings
	SETTINGS_Load();
	
	// Load admins
	ADMINS_Load();
	ADMINS_Create_Default_Admin();

	// Load users
	USERS_Load();

	// Init status leds
	Status_LEDs_Init();
	
	// Init LED CUBE
	LED_CUBE_Init();
	
	UART_CONSOLE_Send_String("Init\n");
}

/*--------------------------- main ------------------------------------------*/

int main (void) {
	//
	// Variables
	//
	char TCP_USER_i = 0;
	TCP_USER_INFO *TCP_USER;
	BOOL TCP_Connected = FALSE;
	
	//
	// Init
	//
  Init();

	// Play saved animation
	if (ANIMATION_PLAY) {
		Animation_Start();
	}
	
	//
	// While
	//

  while (1) {
    timer_poll();
    main_TcpNet();
    DHCP_Check();

		/*****************************************************************************
		** 10 ms timer
		*****************************************************************************/
		
		if (TICK_10MS == __TRUE) {
			TICK_10MS = __FALSE;
			
			if (ANIMATION_PLAY) {
				if (DelayValue >= currentEffect.delay) {
					DelayValue = 0;
					
					if (CurrentAnimationEffect >= AnimationEffectsCount - 1) {
						CurrentAnimationEffect = 0;
					} else {
						CurrentAnimationEffect++;
					}
					
					Animation_Read_Effect();
				} else {
					DelayValue++;
				}
			}
		}
		
		/*****************************************************************************
		** 100 ms timer
		*****************************************************************************/
		
		if (TICK_100MS == __TRUE) {
			TICK_100MS = __FALSE;
			
			if (ANIMATION_PLAY) {
				Status_LED2_Toggle();
			} else {
				Status_LED2_Set(FALSE);
			}
			
			if (TCP_Connected) {
				Status_LED1_Set(TRUE);
			} else {
				Status_LED1_Set(FALSE);
			}
		}
				
		/*****************************************************************************
		** UDP Socket Listener
		*****************************************************************************/
		
		if (UDP_Socket_Listener_Data_Received == TRUE) {
			UDP_Socket_Listener_Data_Received = FALSE; // Clear listener

			switch (UDP_Receive_Check(UDP_Socket_Buffer_Receive, UDP_Socket_Receive_Length)) {
				case PROTOCOL_UDP_ReceiveCheckWhich_search_device:	
						UDP_Socket_Send_Length = UDP_Send_Search_Device(UDP_Socket_Buffer_Send, (char*)DEVICE_IP);
						
						UDP_Socket_Send(UDP_Socket_Buffer_Send, UDP_Socket_Send_Length, UDP_Socket_Remote_IP);
					break;
				default:
					break;
			}
		}
		
		/*****************************************************************************
		** TCP Users Listener
		*****************************************************************************/
		
		TCP_Connected = FALSE;
		
		for (TCP_USER_i=0; TCP_USER_i<TCP_USER_NUMBER_OF_SESSIONS; TCP_USER_i++) {
			TCP_USER = &TCP_USER_SESSIONS[TCP_USER_i];
			
			if (TCP_USER->State == TCP_USER_STATE_CONNECTED) {
				TCP_Connected = TRUE;
			}
			
			/* ------------------- CONNECT ------------------ */
			if (TCP_USER->Connect_Flag == TRUE) {
				TCP_USER->Connect_Flag = FALSE; // Clear interrupt flag

			}

			/* ------------------- DISCONNECT --------------- */
			if (TCP_USER->Disconnect_Flag == TRUE) {
				TCP_USER->Disconnect_Flag = FALSE; // Clear interrupt flag

			}
			
			/* ------------------- RECEIVE ------------------ */
			if (TCP_USER->Received_Flag == TRUE) {
				TCP_USER->Received_Flag = FALSE; // Clear interrupt flag
				
				switch (TCP_Receive_Check(TCP_USER->Buffer_Receive, TCP_USER->Buffer_Receive_Length)) {
					case PROTOCOL_TCP_ReceiveCheckWhich_start_animation:
						AnimationFileName = GetAnimationFileNameFromBuffer(TCP_USER->Buffer_Receive, TCP_USER->Buffer_Receive_Length);
						
						Animation_Start();
						break;
					case PROTOCOL_TCP_ReceiveCheckWhich_stop_animation:
						
						Animation_Stop();
						break;
					case PROTOCOL_TCP_ReceiveCheckWhich_row_set:
						LED_CUBE_Row_Set(TCP_USER->Buffer_Receive[6], TCP_USER->Buffer_Receive[7]);
						break;
					case PROTOCOL_TCP_ReceiveCheckWhich_rows_set:
						LED_CUBE_Rows_Set(TCP_USER->Buffer_Receive[6]);
						break;
					case PROTOCOL_TCP_ReceiveCheckWhich_column_set:
						LED_CUBE_Column_Set(TCP_USER->Buffer_Receive[6], TCP_USER->Buffer_Receive[7]);
						break;
					case PROTOCOL_TCP_ReceiveCheckWhich_columns_set:
						LED_CUBE_Columns_Set(TCP_USER->Buffer_Receive[6], TCP_USER->Buffer_Receive[7], TCP_USER->Buffer_Receive[8], TCP_USER->Buffer_Receive[9],
																 TCP_USER->Buffer_Receive[10], TCP_USER->Buffer_Receive[11], TCP_USER->Buffer_Receive[12], TCP_USER->Buffer_Receive[13]);
						break;
					default:
						break;
				}
			}
		}
		
		/*****************************************************************************
		** UART CONSOLE Listener
		*****************************************************************************/
		
		if (UART_Count[UART_CONSOLE_NUMBER] > 0) {
			UART_RBR_Disable(UART_CONSOLE_NUMBER);
			
			UART_Count[UART_CONSOLE_NUMBER] = 0;
			
			// program

			// ...
			
			// end
			
			UART_RBR_Enable(UART_CONSOLE_NUMBER);
		}
  }
}

/*----------------------------------------------------------------------------
 * end of file
 *---------------------------------------------------------------------------*/

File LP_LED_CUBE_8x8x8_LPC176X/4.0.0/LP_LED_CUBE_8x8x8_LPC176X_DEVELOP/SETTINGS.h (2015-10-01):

/****************************************************************************
	Luka Penger 2013
	SETTINGS
****************************************************************************/
#ifndef __SETTINGS_H 
#define __SETTINGS_H

#include <stdio.h>
#include <RTL.h>
#include <LPC17xx.H>
#include <string.h>
#include <type.h>
#include <stdlib.h>
#include <assert.h>
#include <HELP.h>

#define SETTINGS_FILE_NAME											"device.settings"
#define SETTINGS_FILE_LINE_MAX_LENGTH 					200

// STRINGS

#define SETTINGS_STRINGS_NUMBER 								11

#define DEVICE_NAME 														0
#define FIRMWARE_VERSION												1
#define ETHERNET_MAC_ADDRESS										2
#define IP_ADDRESS															3
#define SUBNET_MASK															4
#define DEFAULT_GATEWAY													5
#define PRI_DNS_ADDRESS													6
#define SEC_DNS_ADDRESS													7
#define DHCP_ENABLE															8
#define PLAYED_ANIMATION_NAME										9
#define PLAYED_ANIMATION												10

void SAVE_PARAMETERS_TO_SETTINGS (void);
void LOAD_SETTINGS_TO_PARAMETERS (void);
void SETTINGS_Load (void);
void SETTINGS_Save (void);

#endif /* end __SETTINGS_H */
/****************************************************************************
                            End Of File
****************************************************************************/
